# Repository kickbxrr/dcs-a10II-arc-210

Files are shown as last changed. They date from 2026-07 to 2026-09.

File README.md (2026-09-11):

# DCS ARC-210 Radio head

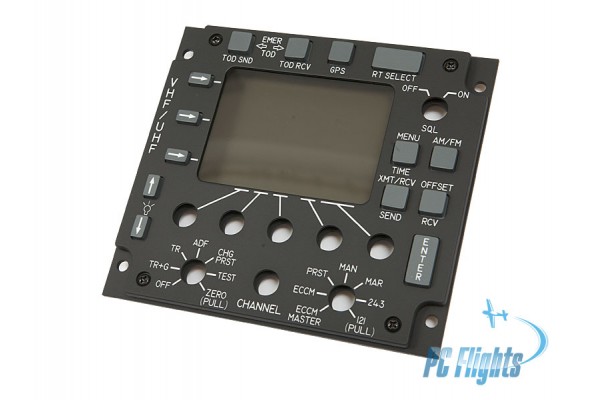
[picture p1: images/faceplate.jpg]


I got this faceplate from **SFSauto** on etsy [A10 ARC210](https://www.etsy.com/listing/1082384231/a10-thunderbolt-left-console-vhf-uhf),
but it seem like either this guy makes them for PC flights.com or got them from them. They are also available
from [PC flights.com](https://pcflights.com), direct link [a-10c-thunderbolt-warthog-vhf-uhf-panel](https://pcflights.com/a-10c-thunderbolt-warthog-vhf-uhf-panel/)

# Summary
This project is a flight sim ARC-210 style radio panel for use with DCS.
The first target interface is USB HID joystick/game-controller input from a Raspberry Pi Pico.

The panel needs to support:
- 14 push buttons
- 7 rotary encoders, without integrated push buttons
- 2 single-pole 8-position rotary switches with 45 degree throw; 7 usable positions each and the eighth mechanically locked out
- Optional SPI display later

# Main design decision
Use the Raspberry Pi Pico for timing-sensitive and analog inputs, and use an I2C I/O expander for the simple push buttons.

There are too many inputs for a clean direct-to-GPIO design on a Raspberry Pi Pico.

Raw direct input count:

- 14 push buttons = 14 digital inputs
- 7 rotary encoders = 14 digital inputs
- 2 rotary switches = 14 digital inputs when only 7 positions per switch are enabled

That would require 42 digital inputs before allowing any pins for an SPI display.
The Pico does not have enough spare GPIO for that approach.

Initeial hardware allocation:

- Raspberry Pi Pico direct GPIO:
  - 7 rotary encoders, 2 GPIO per encoder
  - SPI display pins reserved for future use
  - I2C SDA/SCL for the I/O expander
- Raspberry Pi Pico ADC:
  - 8-position rotary switch 1 through an analog resistor ladder
  - 8-position rotary switch 2 through an analog resistor ladder
  - GP28 / ADC2 **spare**
- MCP23017 I2C I/O expander:
  - 14 push buttons
  - 2 spare expanded digital inputs

# Pico pin allocation
The following allocation keeps all seven encoders on direct Pico GPIO,
places the selector ladders on two of the three exposed ADC pins, and
reserves a complete SPI display interface. Pin numbers in parentheses are
Raspberry Pi Pico physical header pins.

| Function | Pico GPIO | Header pins | Wiring notes |
| --- | --- | --- | --- |
| Encoder 1 | GP0, GP1 | 1, 2 | A, B; encoder common to GND |
| Encoder 2 | GP2, GP3 | 4, 5 | A, B; encoder common to GND |
| MCP23017 I2C | GP4, GP5 | 6, 7 | SDA, SCL; I2C0 at 400kHz |
| Encoder 3 | GP6, GP7 | 9, 10 | A, B; encoder common to GND |
| Encoder 4 | GP8, GP9 | 11, 12 | A, B; encoder common to GND |
| Encoder 5 | GP10, GP11 | 14, 15 | A, B; encoder common to GND |
| Encoder 6 | GP12, GP13 | 16, 17 | A, B; encoder common to GND |
| Encoder 7 | GP14, GP15 | 19, 20 | A, B; encoder common to GND |
| SPI display MISO, CS | GP16, GP17 | 21, 22 | Reserve MISO only if the chosen display supports reads |
| SPI display SCK, MOSI | GP18, GP19 | 24, 25 | SPI0 clock and data output |
| SPI display DC, RST, backlight | GP20, GP21, GP22 | 26, 27, 29 | Backlight pin supports PWM dimming |
| Selector 1 ladder | GP26 / ADC0 | 31 | Switch 1 common/wiper through 1K |
| Selector 2 ladder | GP27 / ADC1 | 32 | Switch 2 common/wiper through 1K |
| Spare GPIO / ADC | GP28 / ADC2 | 34 | Available for future analog or digital input; may be used for an MCP interrupt line |

Power and ground allocation:

- Pico pin 36 `3V3(OUT)` powers the MCP23017 and both resistor ladders.
- Use accessible Pico GND pins for the common ground circuit. Encoder commons, button returns, the MCP23017,
- Pin 33 (`AGND`) is used only for both Resistor ladders.
- Do not put 5V on any Pico GPIO, ADC, MCP23017 logic, or resistor-ladder connection.

Complete Pico wiring allocation

# I/O expander

I used the Waveshare MCP23017 IO Expansion Board I2C. This was a little pricy given the $12 prive per unit.
This is 2x the price of the Pico. There are some alternatives and if you go to a DIP you can find them for
$1.67 as of writing this doc. Using those will be a bit more work. There are also plenty of cheap alternatives
on Amazon, E-bay, Ali-express etc...

I'm using the MCP23017 for push buttons only. Rotary encoders should stay on Pico GPIO because they are timing-sensitive.

The MCP23017 adds 16 digital I/O pins while using only 2 Pico pins for I2C. The Pico remains in
charge: it asks the MCP23017 for its input state over I2C, and the MCP23017 returns a 16-bit value
where each bit represents one expander pin.

How I wired it to the Raspberry Pi Pico:
```text
Pico 3V3  -> MCP23017 VCC
Pico GND  -> MCP23017 GND
Pico SDA  -> MCP23017 SDA
Pico SCL  -> MCP23017 SCL

Each push button:
MCP23017 input pin -> button -> GND
```

Use `GP4` for SDA and `GP5` for SCL. The Arduino sketch configures this I2C0 bus at 400kHz.
The Waveshare board should provide the required I2C pull-ups; do not add more pull-ups until
the board documentation has been checked.

Configure the MCP23017 inputs with internal pull-ups in firmware. No external pull-up resistors
are required for the 14 buttons. A pressed button should read low.

Button state logic:

```text
button not pressed = input reads HIGH / 1
button pressed     = input connected to GND, reads LOW / 0
```

Suggested button pin mapping be based on the exact MCP23017 chip you use. In my original prototype where I just used wires to connect everyting used whatever was convienent

For my PCB, I think I used GPB0-7 and GPA0-5.

MCP23017 14-button wiring

## Polling versus interrupts

Selected approach: poll the MCP23017 every 5ms and debounce each button in firmware for about 20-30ms.

Polling is the preferred first implementation because it needs no additional Pico GPIO or wiring, is easy to debug, and has more than enough response speed for panel buttons. At a 5ms interval, a press is seen within 5ms before debounce; the I2C traffic and Pico CPU cost are negligible.

The MCP23017 interrupt outputs are useful only if future firmware needs to avoid idle I2C reads, put the Pico to sleep, or manages several expanders. Interrupts add an extra wire and more firmware state: switch bounce can cause repeated interrupts, and the Pico must read the MCP23017 `GPIO` or `INTCAP` register to clear the asserted interrupt.

Do not wire the interrupt output for the first version. A future version can connect mirrored, open-drain `INTA`/`INTB` to spare `GP28`, with a 3.3V pull-up, if interrupt-driven input becomes useful.

Button event flow:

```text
Button press
  -> MCP23017 input pin goes LOW
  -> Pico reads MCP23017 over I2C
  -> Pico sees that bit changed from 1 to 0
  -> Pico debounces the change
  -> Pico sends USB HID joystick button pressed to DCS
```

Run the MCP23017 board at 3.3V with the Pico. Keeping the control wiring at 3.3V avoids level-safety issues because Pico GPIO are not 5V tolerant.

I picked the Waveshare board over a generic MCP23017 module because it is documented, exposes address selection, and exposes interrupt pins. The interrupt pins are optional; simple polling is acceptable for push buttons.

Multiple MCP23017 boards can share the same Pico I2C bus if they have different I2C addresses. The MCP23017 supports address selection with A0/A1/A2, which allows up to 8 MCP23017 devices on the same bus.

# 8-position rotary switches (seven enabled positions)

The two 8-position switches are single-pole 8-position rotary switches.

Known switch specifications:

- Voltage rating: 125V
- Current rating: 2.5A AC, 350mA DC
- Actuator type: flatted, 6.35mm diameter
- Actuator length: 38mm
- Depth behind panel: 14.48mm
- Panel cutout: circular, 9.80mm diameter
- Number of positions: 8
- Angle of throw: 45 degrees

Recommended wiring approach: use each switch as an ADC resistor ladder so each rotary switch consumes
one Pico ADC input instead of seven digital inputs.

The eighth physical switch position is mechanically locked out. The circuit therefore provides
seven valid selector readings. Wire the disabled eighth throw to GND as an invalid diagnostic value,
rather than leaving it floating.

## Resistor ladder concept
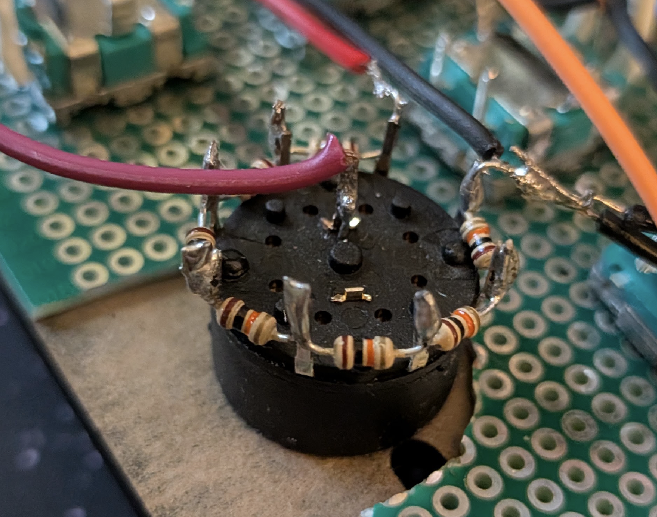
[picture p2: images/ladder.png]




The Pico ADC reads voltage. A resistor ladder creates a set of known voltages between 3.3V and GND. The rotary switch selects one of those voltage taps and sends it to the ADC input.

Use one resistor ladder per switch. The two switches cannot share a ladder because each common/wiper needs an independent ADC voltage at the same time.

Resistor ladder:
```text
3V3
 |
[10k]
 |---- switch throw 7  ~2.89V
[10k]
 |---- switch throw 6  ~2.48V
[10k]
 |---- switch throw 5  ~2.06V
[10k]
 |---- switch throw 4  ~1.65V
[10k]
 |---- switch throw 3  ~1.24V
[10k]
 |---- switch throw 2  ~0.83V
[10k]
 |---- switch throw 1  ~0.41V
[10k]
 |
GND
```

The switch common/wiper is the output:

```text
Switch common/wiper -> 1k resistor -> Pico ADC input
Pico ADC input -> 100nF capacitor -> GND
```

The 1k resistor protects the ADC input from brief wiring or contact transients. The 100nF capacitor smooths noise and contact chatter, and provides a low-impedance source while the Pico ADC samples. A pulldown is not required. Do not use a 100k pulldown: it would load the ladder and shift the expected voltages. A 1M pulldown is optional only if it is bought separately.

## Recommended parts

For each rotary switch:

- 8x 10k ohm resistors, for the ladder
- Small perfboard or stripboard
- 24-26 AWG hookup wire
- *Optional* 3-pin connector for 3V3, GND, and ADC signal

Use the available 10k resistors for the ladder in series with the ADC. With 8 x 10k resistors,
the ladder is 80k total and draws about 41uA from 3.3V. The voltage steps are wide enough for
reliable detection while keeping current draw low.

## Assembly steps
1. Use a multimeter to identify the switch common/wiper pin.
2. Build the 8-resistor chain on a small perfboard.
3. Connect the top of the chain to Pico 3V3.
4. Connect the bottom of the chain to the common ground circuit that returns to Pico physical pin 23.
5. Run one wire from each of the seven ladder taps to the corresponding active switch throw terminal.
6. Run the switch common/wiper through a 1k resistor to the Pico ADC pin.
7. Put a 100nF capacitor from the ADC pin side of the 1k resistor to GND.
8. Wire the locked-out eighth switch terminal directly to GND so it decodes as an invalid position if it is ever reached.
9. In firmware, read the ADC and map voltage ranges to positions 1-7.

**Suggested** Pico ADC allocation:

```text
Switch 1 common/wiper -> Pico GP26 / ADC0
Switch 2 common/wiper -> Pico GP27 / ADC1
Spare                  -> Pico GP28 / ADC2
```

## Expected ADC values
For a 12-bit ADC reading from 0-4095, approximate values are:

```text
Position 1:  512
Position 2: 1024
Position 3: 1536
Position 4: 2048
Position 5: 2559
Position 6: 3071
Position 7: 3583
Locked-out position: approximately 0 (invalid)
```

Firmware should define threshold ranges for each position instead of checking exact values. A good starting point is to place each threshold halfway between adjacent expected values, then require the decoded position to remain stable for 20-50ms before accepting the change.

## Interface to DCS

Initial recommendation: USB HID joystick/game-controller firmware using Arduino with the Arduino-Pico core.

Benefits:

- Simple host-side setup
- DCS can bind buttons, encoders, and selector pulses through normal controller bindings
- No DCS-specific protocol required for the first version

DCS-BIOS may be worth considering later if the project needs bidirectional state, display synchronization, 
or aircraft-specific radio data. this will be necvessary when the SPI display is added.

# Firmware stack

Selected stack: Arduino IDE with the Arduino-Pico core.

This is the final firmware environment because the project is a USB HID game-controller device. Arduino-Pico provides
a familiar sketch workflow while retaining C++ performance and offering built-in 
USB joystick, keyboard, and mouse support. It is a practical fit on both Windows 11 and macOS. Also I am more familar with 
the C++ environment of Arduino than Python or CMake.

Suggested implementation order:

1. Bring up the Pico in Arduino IDE with the Arduino-Pico board package.
2. Scan the I2C bus and confirm the MCP23017 address, expected to be `0x27` unless its address jumpers are changed. this got me at first since the AI wanted it to be `0x20` and I had to do a lot of looking up the datasheet to find the right address.
3. Configure the 14 MCP23017 pins as `INPUT_PULLUP`; poll both ports every 5ms and debounce button state changes for 20-30ms.
4. Read the two selector ADC inputs; decode selector positions by threshold range and require a stable reading for 20-50ms.
5. Read the seven encoders directly from Pico GPIO.
6. Send button, selector, and encoder events through USB HID to DCS.

Why Arduino-Pico instead of the Pico SDK:

- Arduino-Pico is C++ with a straightforward sketch, library, compile, and upload workflow. It is easier to iterate on than a standalone CMake project.
- It already provides the USB HID joystick/game-controller capability this panel needs.
- The Pico SDK provides the most control over low-level timing and custom USB descriptors, but its toolchain and CMake project setup are more involved. It remains a good future option if this panel eventually needs a custom HID report beyond what Arduino-Pico provides.

Windows 11 and macOS are both suitable for Arduino-Pico. The finished Pico appears to the computer as a standard USB HID device, so DCS does not need a special driver.

## Initial controller sketch
The initial Arduino sketch is [arc210_controller.ino](./arc210_controller/arc210_controller.ino).

Arduino IDE setup:

1. Install the Arduino-Pico board package and select `Raspberry Pi Pico`.
2. Set `Tools -> USB Stack -> Pico SDK`; the Arduino-Pico `Joystick` library is provided by this USB stack.
3. Install `Adafruit MCP23X17` from Library Manager. Its dependencies, including Adafruit BusIO, should install automatically.
4. Upload the sketch with the Pico connected by USB.

The sketch presents one USB joystick with all 32 buttons used and no analog control assigned:

| HID controls | Source |
| --- | --- |
| Buttons 1-14 | MCP23017 push buttons |
| Buttons 15-26 | Encoder 1-6 positive and negative turns |
| Buttons 27-28 | Encoder 7 positive and negative turns |
| Buttons 29-30 | Selector 1 next and previous position pulses |
| Buttons 31-32 | Selector 2 next and previous position pulses |

The Arduino-Pico joystick descriptor supports 32 buttons, so this allocation uses its entire button capacity. The selectors intentionally emit relative next/previous pulses instead of using fourteen more held buttons, keeping the design within that limit. Bind each selector's next/previous buttons to the matching DCS increment/decrement commands. On startup, align the simulator state with the physical selector positions manually.

## Open items before final schematic

- SPI display model and pin requirements
- Find suitable display

## Initial Prototype
The initial prototype was done on perf boards. I found ut the hard way that drilling and cutting perfboards can have 
some consequences.The worse was getting a few fiberglass splinters. The Pico was mounted on 2 1x20 sockets 
(Technically it was 4 1x10 connectors that I sanded to fit and work like 2 1x20 connectors), and the MCP23017 
was mounted on 2 1x10 connectors.The components are just soldiered together using random wires. the whole thing 
is kind of a mess. It works but it is ugly.

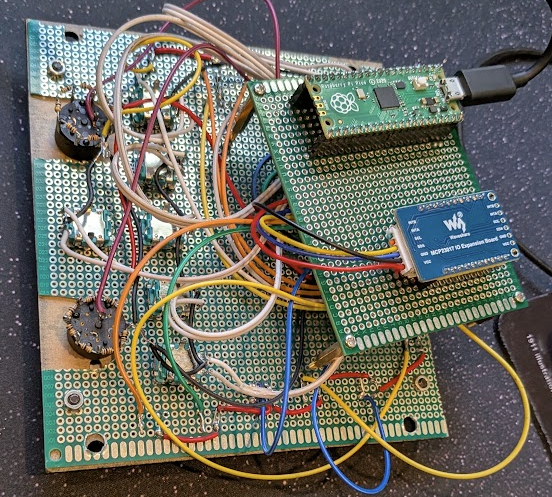
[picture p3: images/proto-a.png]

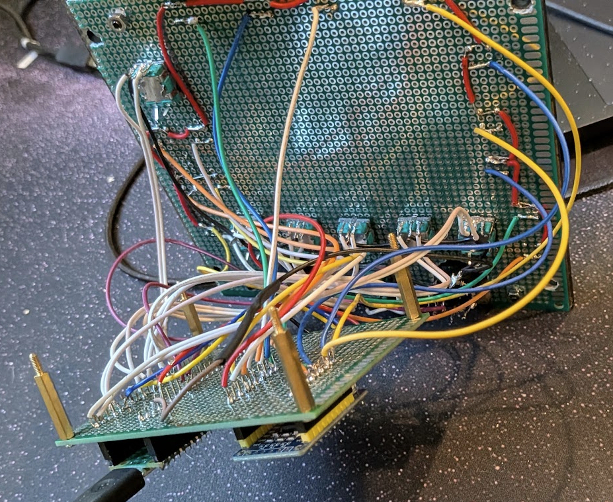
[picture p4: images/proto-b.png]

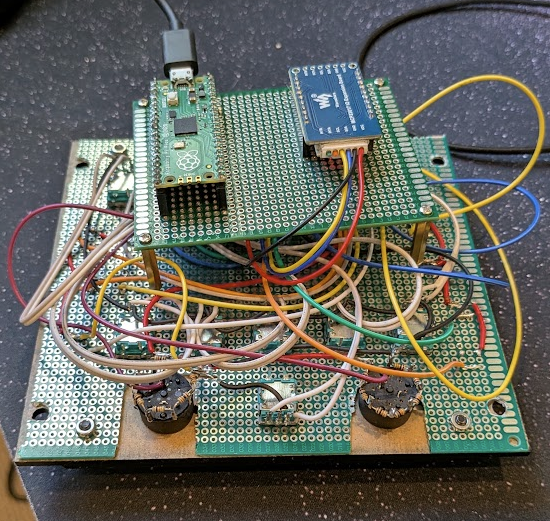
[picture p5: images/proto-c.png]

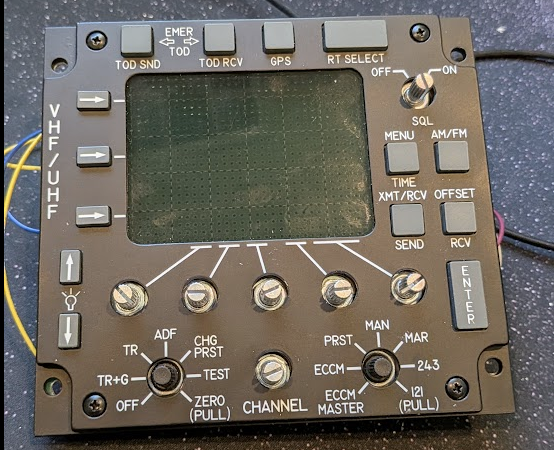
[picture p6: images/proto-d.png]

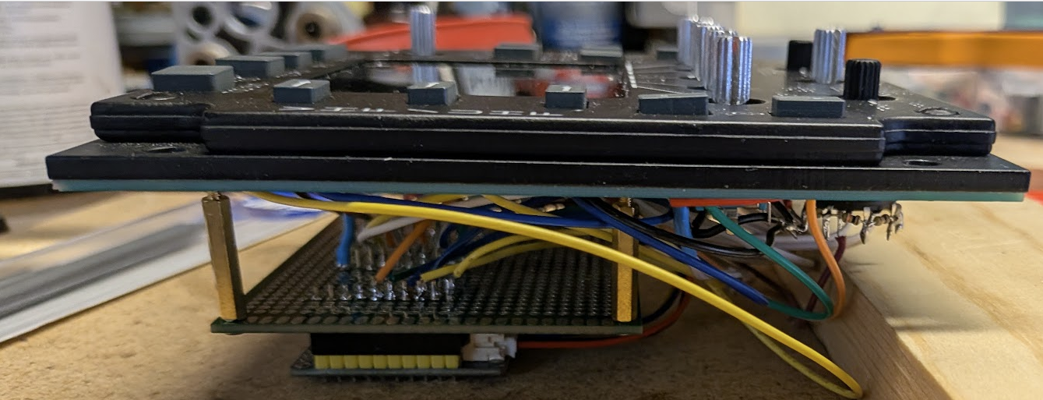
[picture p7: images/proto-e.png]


# Phase 2 PCB
I figured it would be cool to see if I can create a PCB.
Watching some youtube videos from the Warthog project and
some DCS community videos of people build button boxes and
different panels made me think I could clean this up a lot.

# Schematic
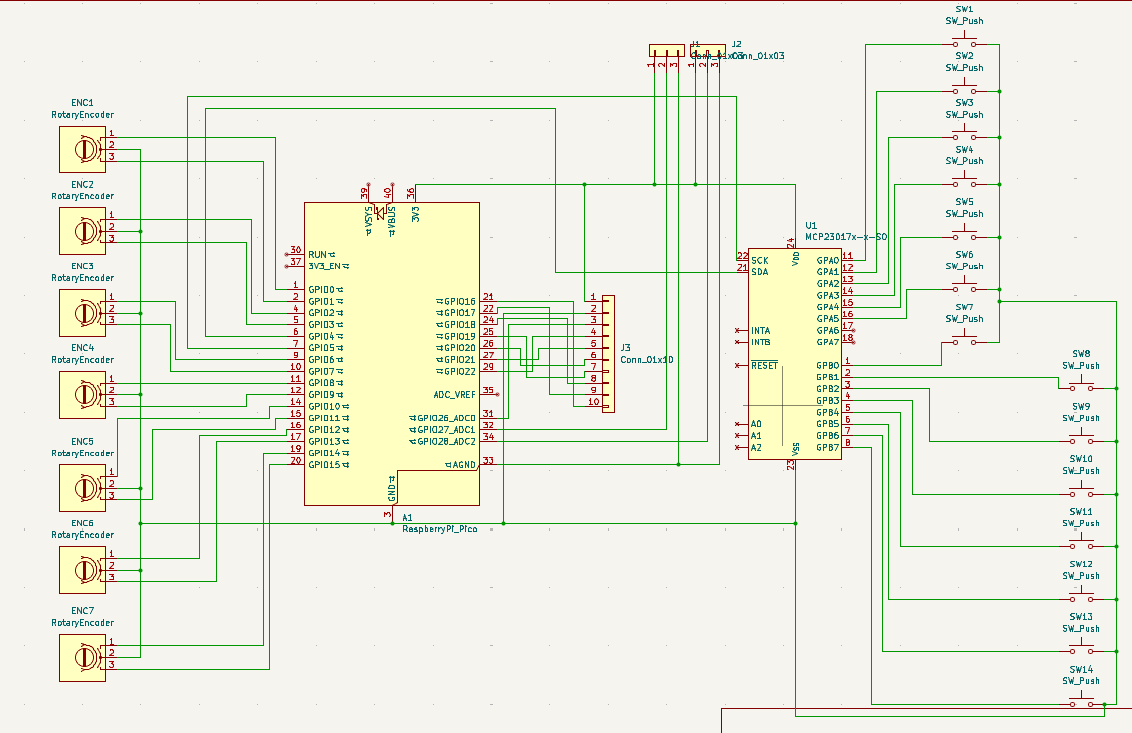
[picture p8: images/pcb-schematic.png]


## PCB Rev B work

The first PCB revision is a panel-sized button carrier. The 14 tactile
buttons mount directly to the PCB; the seven encoders and two selectors
remain faceplate-mounted and connect through cutouts in the PCB. Maybe if
I try to do another prototype I will try surface mounting the compnenets
and try to get an assempled board with all the part already on the board. 
this feel like a big leap from I was hand ouldering crap from perfboards with
a rats nest of wires 3 weeks ago to producing a full PCBA board

Rev B uses a removable Raspberry Pi Pico in two 1x20 sockets,
a socketed MCP23017-E/SP DIP-28 IC, and provisional 6x6mm
tactile-switch footprints. It was ready for fabrication pretty quick.
I', pretty sure my trace routing needs some help, but all the button work
as expected so that is a win in my book.

## Kicad
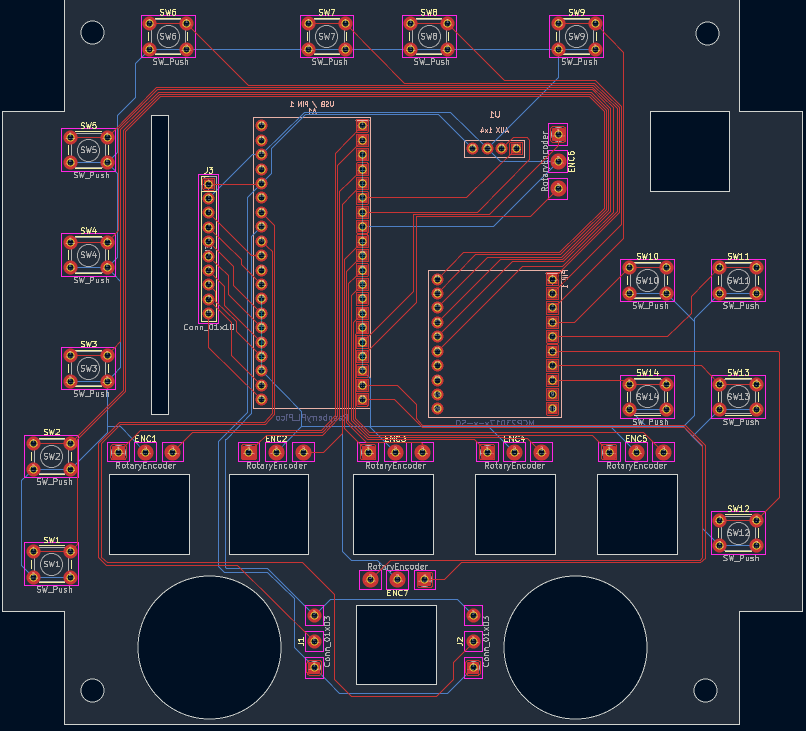
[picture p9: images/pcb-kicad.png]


### 3D Front
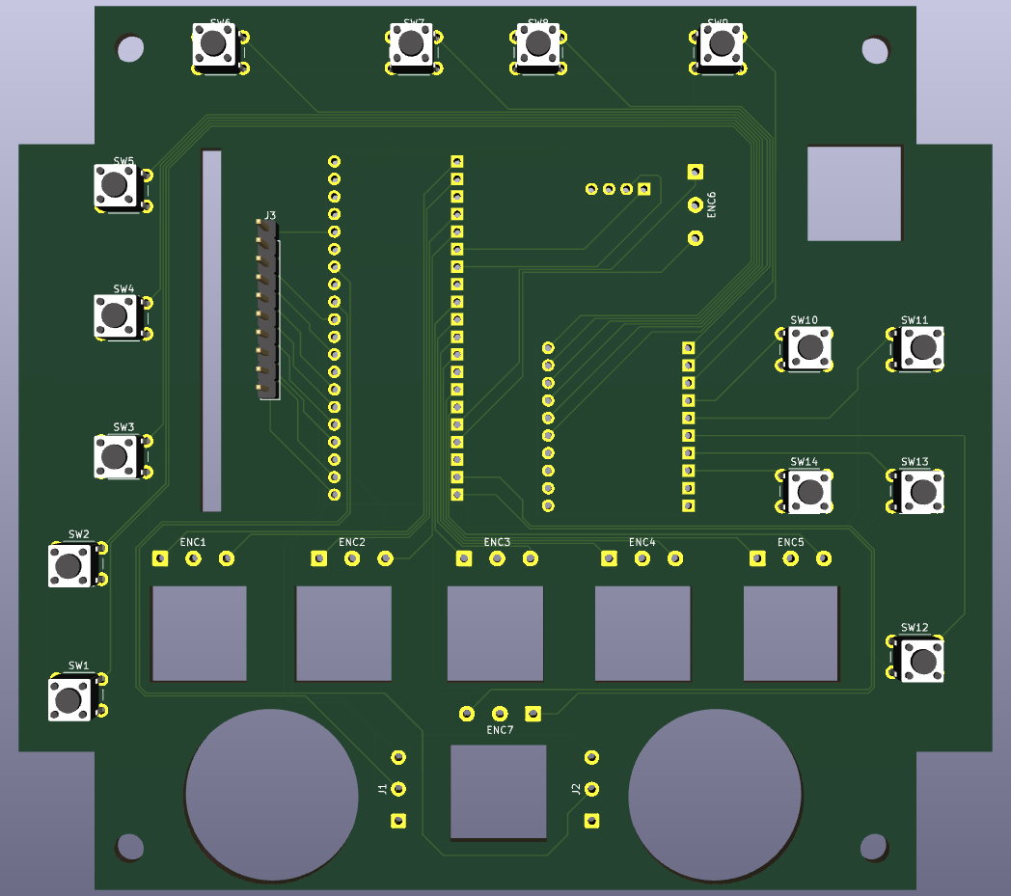
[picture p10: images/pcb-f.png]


### 3d Back
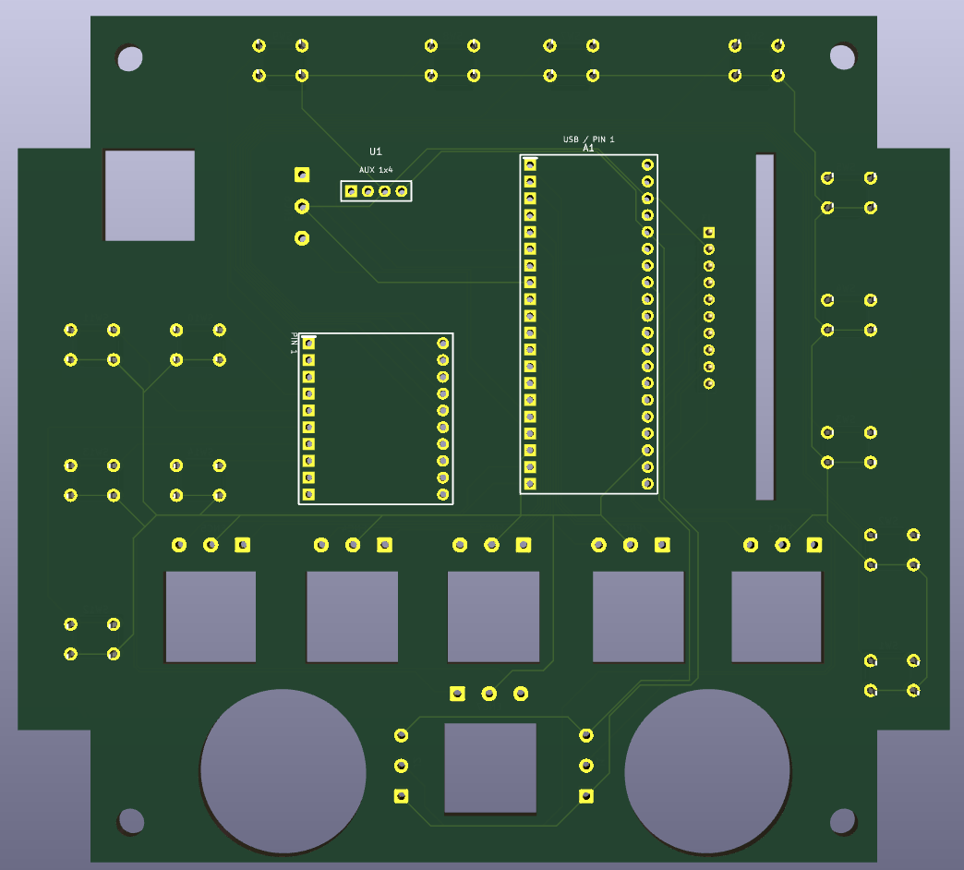
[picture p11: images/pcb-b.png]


### Actual PCB Front
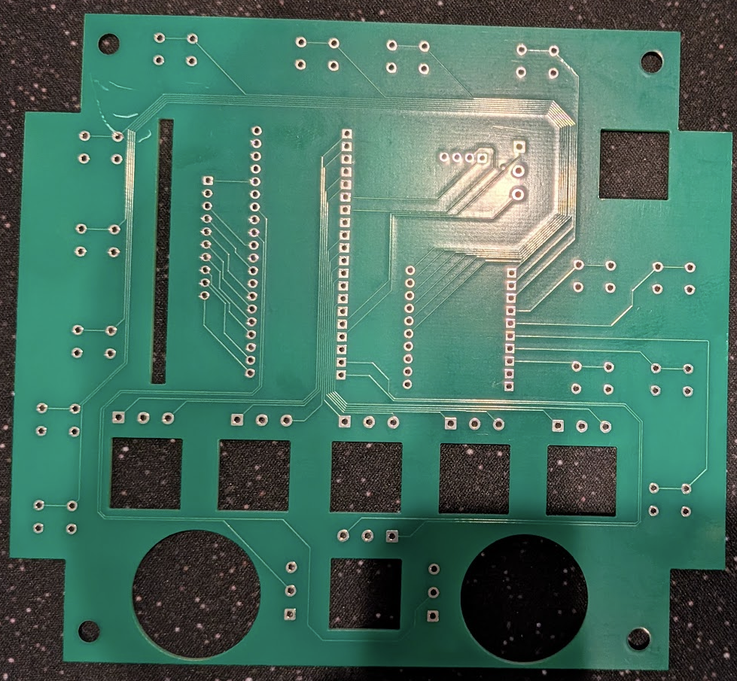
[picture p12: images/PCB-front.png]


### Actual PCB Back
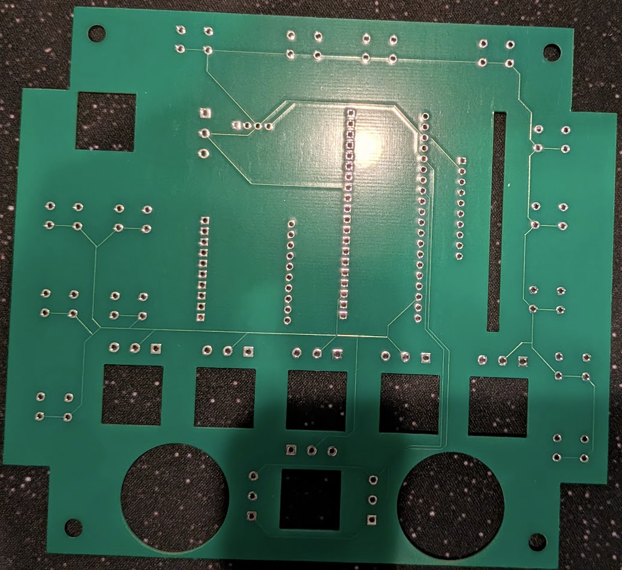
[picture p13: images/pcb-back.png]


## SPI display `Phase 3`
The design reserves pins for a SPI display. A typical SPI display may need:

- SCK
- MOSI
- CS
- DC
- optional RST
- optional backlight control

Using the MCP23017 for push buttons keeps enough Pico pins available for the display.
Direct-to-GPIO wiring for all buttons and switch positions would make the SPI display
difficult to add if impossible.

For the display I get a 3.5" TFT display from Amazon. I did some surgery to remove the display
from the controller board. I figured I would destroy one of the two boards but in a stroke of luck
I got it sorted out on the 1st try.

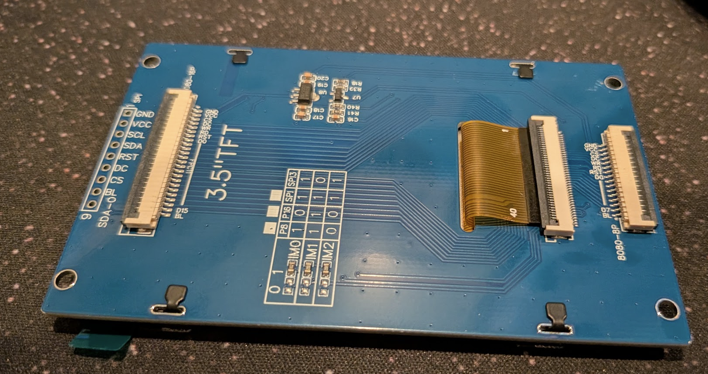
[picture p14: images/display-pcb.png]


# How did it all turn out?
TBD!!!

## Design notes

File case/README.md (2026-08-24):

# ARC-210 open-top tray

`arc210_open_tray.scad` is an editable OpenSCAD model for a 3D-printed case:

- Overall size: 146 mm wide x 133 mm high x 40 mm deep
- Wall thickness: 2 mm
- Floor thickness: 3 mm
- Open top
- 2 mm outside corner radius, matching the SVG outline
- Four 28 mm-deep corner mounting features: an 8 mm top pad plus a 20 mm
  wall-to-pad transition at 45° or steeper, with 6 mm-rounded inside corners
- Four 6 mm through-holes at the SVG's M1-M4 locations; each passes through
  the full 8 mm mounting pad

## Exporting an STL

1. Open `arc210_open_tray.scad` in OpenSCAD.
2. Press **F6** to render the model.
3. Choose **File → Export → Export as STL**.

The hole locations, diameter, pad thickness, and gusset depth are parameters
near the top of the SCAD file and can be changed before exporting.

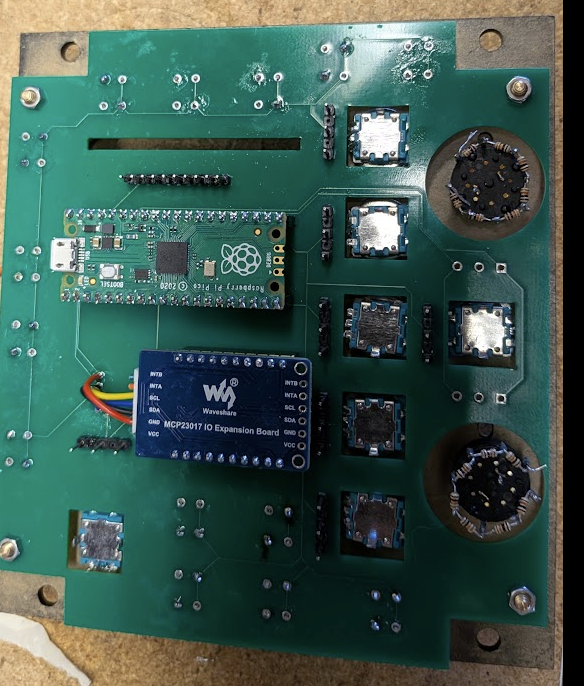
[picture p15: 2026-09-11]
images/proto-b-3.png

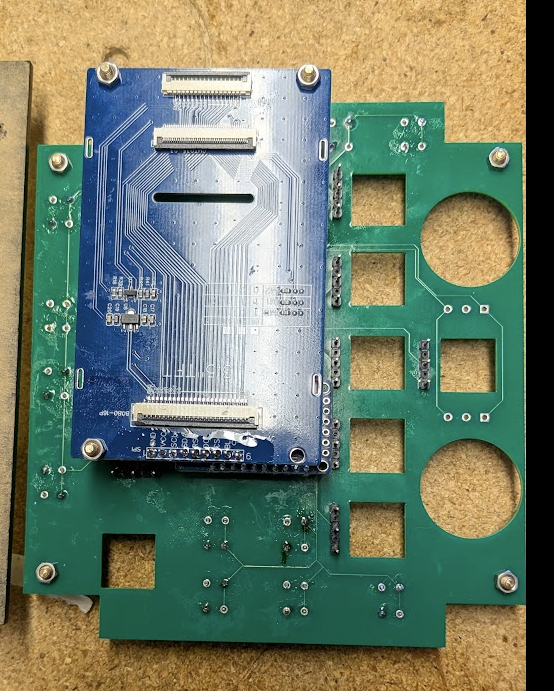
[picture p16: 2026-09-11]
images/proto-b.1-1.png

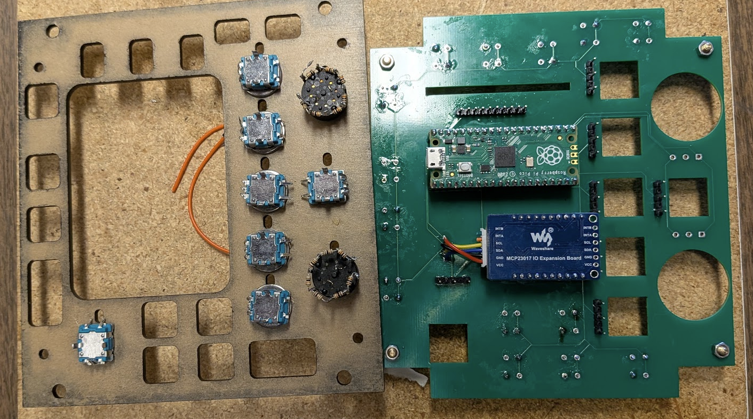
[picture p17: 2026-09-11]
images/proto-b-1.png

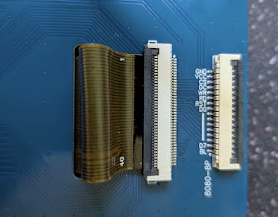
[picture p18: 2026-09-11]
images/proto-zif.png

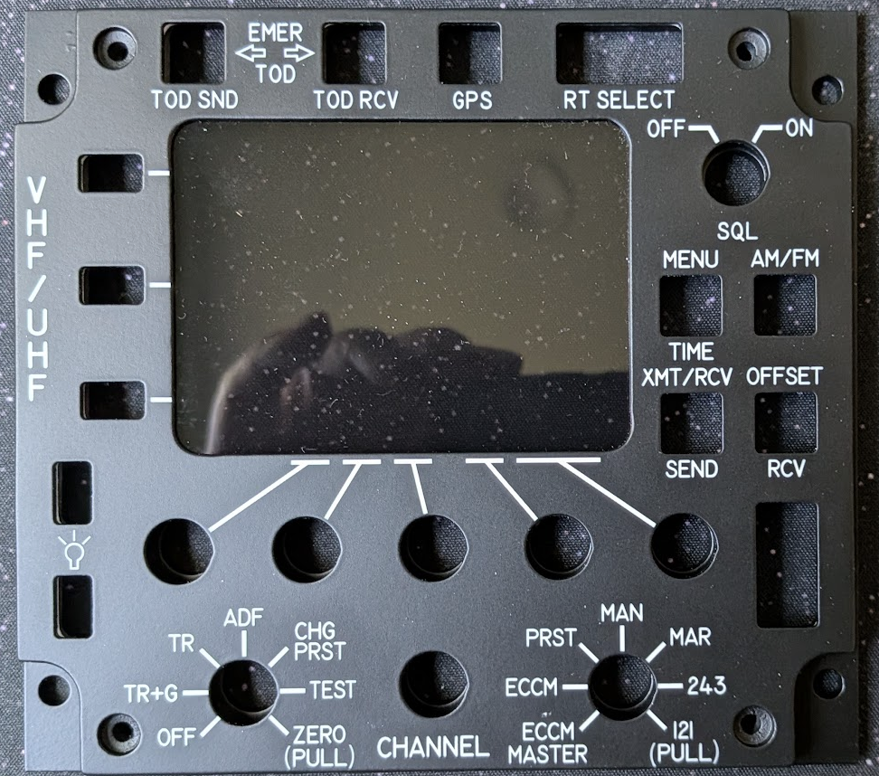
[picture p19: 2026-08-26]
images/faceplate-actual.png

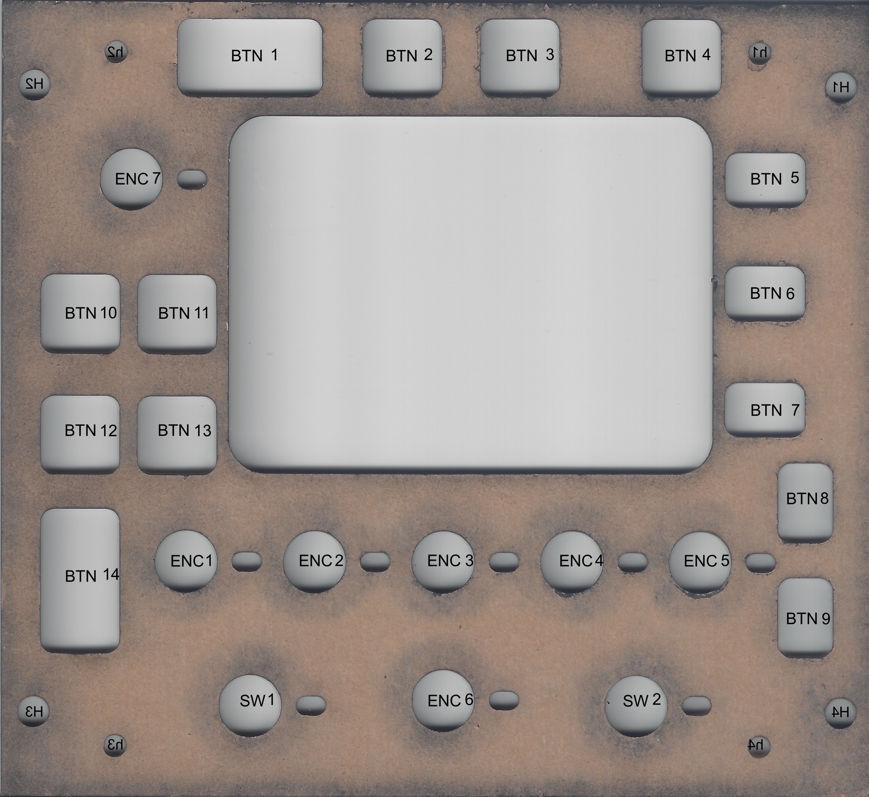
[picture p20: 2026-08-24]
images/scanofbackplate.jpg

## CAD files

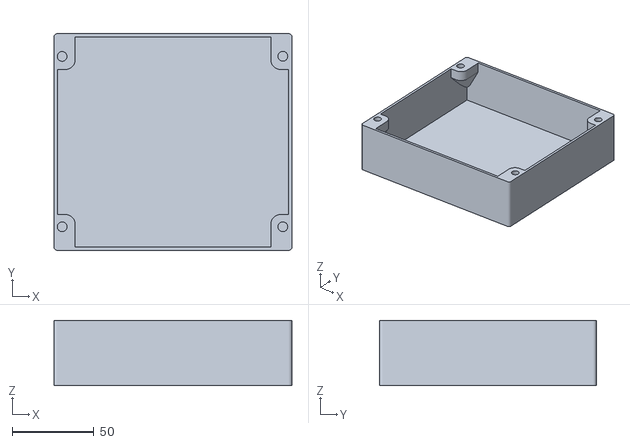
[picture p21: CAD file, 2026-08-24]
case/arc210_open_tray.stl
146.0 x 133.0 x 40.0

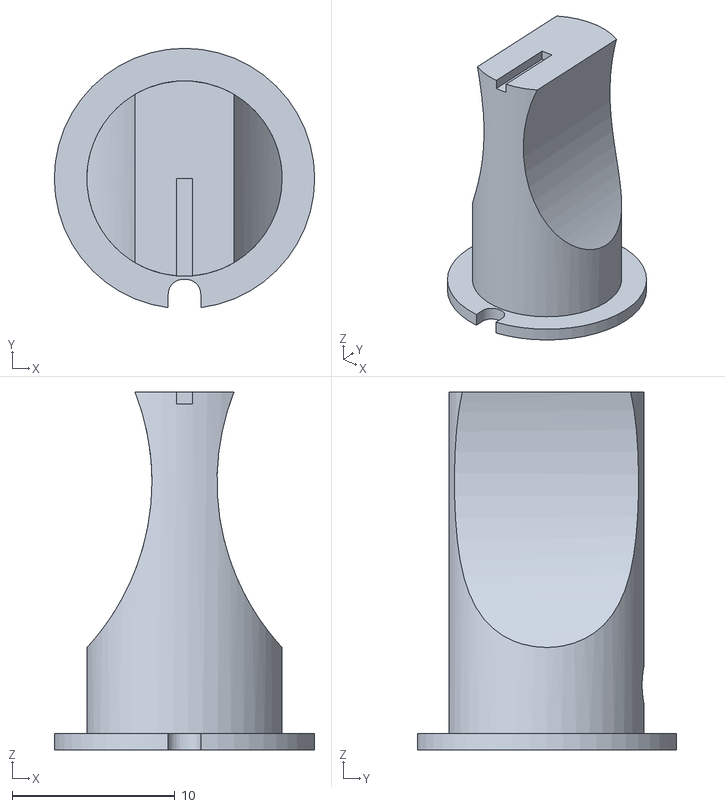
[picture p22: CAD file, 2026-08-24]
knobs/ARC-210_Mode_Knob_shaft-depth-8.2mm.stl
16.0 x 15.9 x 22.0

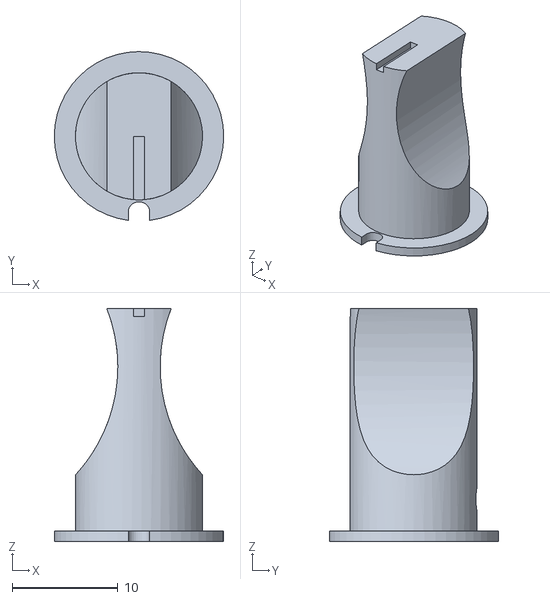
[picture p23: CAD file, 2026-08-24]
knobs/ARC-210 Mode Knob.stl
16.0 x 15.9 x 22.0

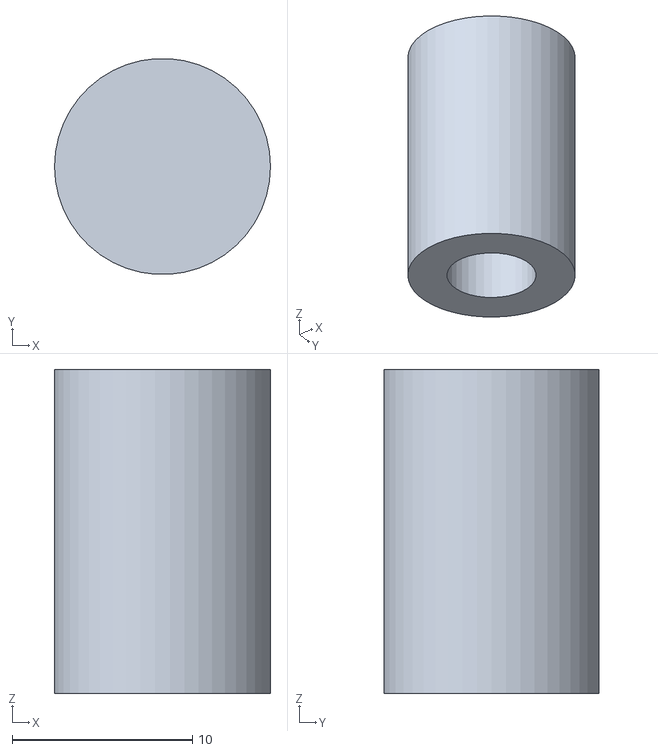
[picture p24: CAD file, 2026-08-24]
knobs/ARC-210 Channel Knob.stl
12.0 x 12.0 x 18.0

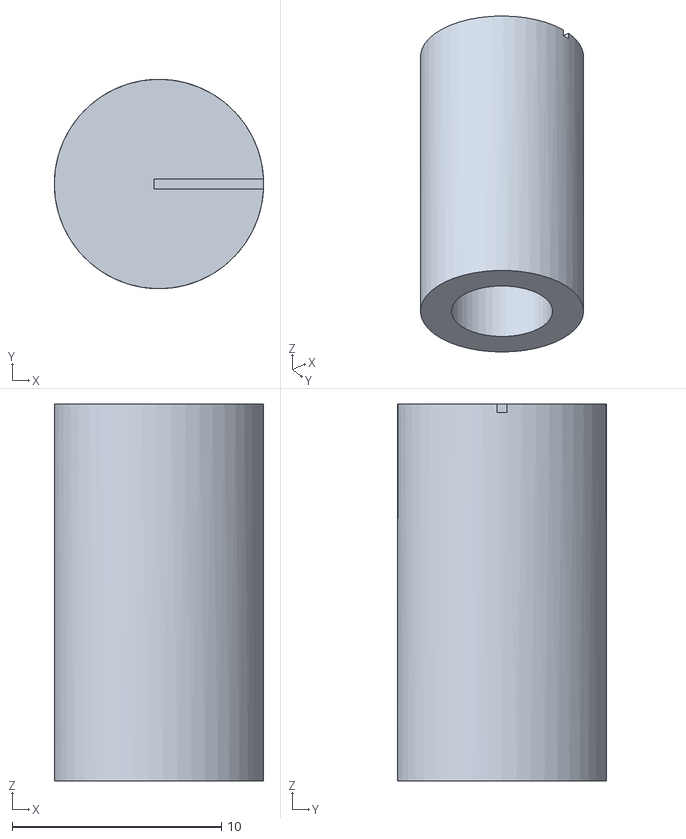
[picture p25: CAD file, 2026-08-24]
knobs/ARC-210 Squelch Knob.stl
10.0 x 10.00 x 18.0

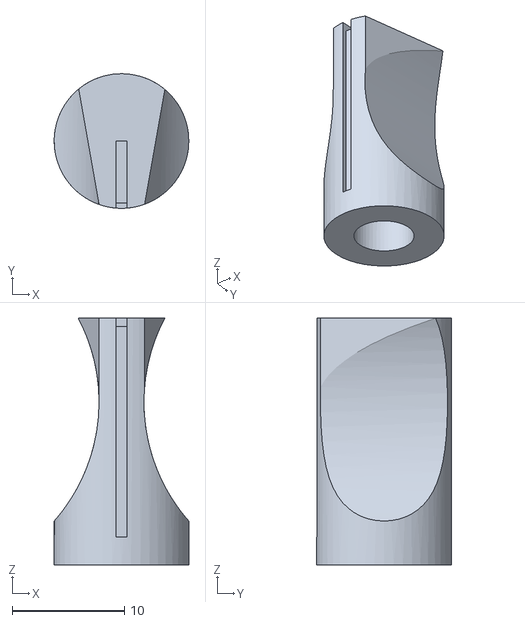
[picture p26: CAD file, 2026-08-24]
knobs/ARC-210 Freq Knob.stl
12.0 x 12.0 x 22.0

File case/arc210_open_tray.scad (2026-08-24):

// ARC-210 shallow open-top case
// Units: millimetres
// The XY outline matches the 146 x 133 mm faceplate template; Z is depth.

outer_width = 146;
outer_height = 133;
case_depth = 40;
wall_thickness = 2;
floor_thickness = 3;
outer_corner_radius = 2;

// Through-holes matching the M1-M4 locations in the SVG. They pass through
// the upper mounting pads from the open/top face.
mounting_hole_diameter = 6;  // SVG radius is 3 mm
mounting_feature_depth = 28; // 20 mm taper + 8 mm top pad
mounting_pad_thickness = 8;  // flat top pad; holes pass through this section
mounting_gusset_height = mounting_feature_depth - mounting_pad_thickness;
mounting_holes = [
    [5.0, 14.5],    // M1
    [140.4, 14.5],  // M2
    [5.0, 119.0],   // M3
    [140.4, 119.1]  // M4
];

// The SVG's four black mounting blocks are clipped 26 x 44 mm rounded
// rectangles whose centres sit on the corners of the faceplate.
corner_block_width = 26;
corner_block_height = 44;
corner_block_radius = 6;
corner_blocks = [
    [-13, -22],
    [133, -22],
    [-13, 111],
    [133, 111]
];
corner_outward_shifts = [
    [-11, -20],
    [11, -20],
    [-11, 20],
    [11, 20]
];

module rounded_rectangle(size, radius) {
    translate([radius, radius])
        offset(r = radius)
            square([size[0] - 2*radius, size[1] - 2*radius]);
}

module outer_profile() {
    rounded_rectangle([outer_width, outer_height], outer_corner_radius);
}

module wall_profile() {
    // The 2 mm perimeter walls continue through the full case depth.
    intersection() {
        outer_profile();
        union() {
            square([outer_width, wall_thickness]);
            translate([0, outer_height - wall_thickness])
                square([outer_width, wall_thickness]);
            square([wall_thickness, outer_height]);
            translate([outer_width - wall_thickness, 0])
                square([wall_thickness, outer_height]);
        }
    }
}

module corner_profile(p) {
    intersection() {
        outer_profile();
        translate(p)
            rounded_rectangle(
                [corner_block_width, corner_block_height],
                corner_block_radius);
    }
}

module mounting_profile() {
    // Full mounting-pad footprint, used for the top 8 mm.
    intersection() {
        outer_profile();
        union() {
            for (p = corner_blocks)
                corner_profile(p);
        }
    }
}

module mounting_gussets() {
    // Each gusset starts at the inside faces of the 2 mm walls and grows to
    // the pad over 20 mm of height. The limiting direction is exactly 45°;
    // the other direction is steeper and therefore also support-free.
    for (i = [0 : len(corner_blocks) - 1])
        hull() {
            p = corner_blocks[i];
            s = corner_outward_shifts[i];
            translate([0, 0, case_depth - mounting_feature_depth])
                linear_extrude(height = 0.01)
                    corner_profile([p[0] + s[0], p[1] + s[1]]);
            translate([0, 0, case_depth - mounting_pad_thickness])
                linear_extrude(height = 0.01)
                    corner_profile(p);
        }
}

module case_body() {
    difference() {
        union() {
            // Full outer-profile floor, full-height walls, and upper pads.
            linear_extrude(height = floor_thickness)
                outer_profile();
            linear_extrude(height = case_depth)
                wall_profile();
            translate([0, 0, case_depth - mounting_pad_thickness])
                linear_extrude(height = mounting_pad_thickness)
                    mounting_profile();
            mounting_gussets();
        }

        // Through-holes in the upper 8 mm mounting pads. The small overlap at
        // either end guarantees a clean cut through the pad surfaces.
        for (p = mounting_holes)
            translate([p[0], p[1], case_depth - mounting_pad_thickness - 0.1])
                cylinder(h = mounting_pad_thickness + 0.2,
                         d = mounting_hole_diameter,
                         $fn = 48);
    }
}

case_body();

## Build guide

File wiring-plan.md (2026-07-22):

# ARC-210 wiring plan

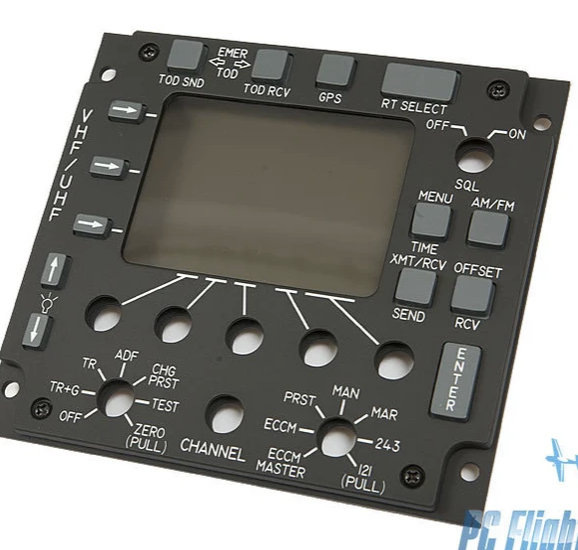
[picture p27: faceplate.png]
panel


# Summary

This project is a flight sim ARC-210 style radio panel for use with DCS. The first target interface is USB HID joystick/game-controller input from a Raspberry Pi Pico.

The panel needs to support:

- 14 push buttons
- 7 rotary encoders, without integrated push buttons
- 2 single-pole 8-position rotary switches with 45 degree throw; 7 usable positions each and the eighth mechanically locked out
- Optional SPI display later

# Main design decision

There are too many inputs for a clean direct-to-GPIO design on a Raspberry Pi Pico.

Raw direct input count:

- 14 push buttons = 14 digital inputs
- 7 rotary encoders = 14 digital inputs
- 2 rotary switches = 14 digital inputs when only 7 positions per switch are enabled

That would require 42 digital inputs before allowing any pins for an SPI display. The Pico does not have enough spare GPIO for that approach.

# Recommended architecture

Use the Pico for timing-sensitive and analog inputs, and use an I2C I/O expander for the simple push buttons.

Recommended allocation:

- Raspberry Pi Pico direct GPIO:
  - 7 rotary encoders, 2 GPIO per encoder
  - SPI display pins reserved for future use
  - I2C SDA/SCL for the I/O expander
- Raspberry Pi Pico ADC:
  - 8-position rotary switch 1 through an analog resistor ladder
  - 8-position rotary switch 2 through an analog resistor ladder
  - GP28 / ADC2 remains spare
- MCP23017 I2C I/O expander:
  - 14 push buttons
  - 2 spare expanded digital inputs

# Exact Pico pin allocation

The following allocation keeps all seven encoders on direct Pico GPIO, places the selector ladders on two of the three exposed ADC pins, and reserves a complete SPI display interface. Pin numbers in parentheses are Raspberry Pi Pico physical header pins.

| Function | Pico GPIO | Header pins | Wiring notes |
| --- | --- | --- | --- |
| Encoder 1 | GP0, GP1 | 1, 2 | A, B; encoder common to GND |
| Encoder 2 | GP2, GP3 | 4, 5 | A, B; encoder common to GND |
| MCP23017 I2C | GP4, GP5 | 6, 7 | SDA, SCL; I2C0 at 400kHz |
| Encoder 3 | GP6, GP7 | 9, 10 | A, B; encoder common to GND |
| Encoder 4 | GP8, GP9 | 11, 12 | A, B; encoder common to GND |
| Encoder 5 | GP10, GP11 | 14, 15 | A, B; encoder common to GND |
| Encoder 6 | GP12, GP13 | 16, 17 | A, B; encoder common to GND |
| Encoder 7 | GP14, GP15 | 19, 20 | A, B; encoder common to GND |
| SPI display MISO, CS | GP16, GP17 | 21, 22 | Reserve MISO only if the chosen display supports reads |
| SPI display SCK, MOSI | GP18, GP19 | 24, 25 | SPI0 clock and data output |
| SPI display DC, RST, backlight | GP20, GP21, GP22 | 26, 27, 29 | Backlight pin supports PWM dimming |
| Selector 1 ladder | GP26 / ADC0 | 31 | Switch 1 common/wiper through 1K |
| Selector 2 ladder | GP27 / ADC1 | 32 | Switch 2 common/wiper through 1K |
| Spare GPIO / ADC | GP28 / ADC2 | 34 | Available for future analog or digital input; may be used for an MCP interrupt line |

Power and ground allocation:

- Pico pin 36 `3V3(OUT)` powers the MCP23017 and both resistor ladders.
- Use accessible Pico GND pin 23 for the common ground circuit. Pin 33 (`AGND`) is not used. Encoder commons, button returns, the MCP23017, both selector ladders, and their 100nF capacitors may all share this ground circuit. If selector readings later prove noisy, shorten their signal and ground wiring before making larger wiring changes.
- Do not put 5V on any Pico GPIO, ADC, MCP23017 logic, or resistor-ladder connection.

Complete Pico wiring allocation

# I/O expander

Recommended part: Waveshare MCP23017 IO Expansion Board I2C.

Use the MCP23017 for push buttons only. Rotary encoders should stay on Pico GPIO because they are timing-sensitive.

The MCP23017 adds 16 digital I/O pins while using only 2 Pico pins for I2C. The Pico remains in charge: it asks the MCP23017 for its input state over I2C, and the MCP23017 returns a 16-bit value where each bit represents one expander pin.

Suggested wiring:

```text
Pico 3V3  -> MCP23017 VCC
Pico GND  -> MCP23017 GND
Pico SDA  -> MCP23017 SDA
Pico SCL  -> MCP23017 SCL

Each push button:
MCP23017 input pin -> button -> GND
```

Use `GP4` for SDA and `GP5` for SCL. The Arduino sketch configures this I2C0 bus at 400kHz. The Waveshare board should provide the required I2C pull-ups; do not add more pull-ups until the board documentation has been checked.

Configure the MCP23017 inputs with internal pull-ups in firmware. No external pull-up resistors are required for the 14 buttons. A pressed button should read low.

Button state logic:

```text
button not pressed = input reads HIGH / 1
button pressed     = input connected to GND, reads LOW / 0
```

Suggested button pin mapping:

```text
Button 1  -> MCP23017 GPA0
Button 2  -> MCP23017 GPA1
Button 3  -> MCP23017 GPA2
Button 4  -> MCP23017 GPA3
Button 5  -> MCP23017 GPA4
Button 6  -> MCP23017 GPA5
Button 7  -> MCP23017 GPA6
Button 8  -> MCP23017 GPA7

Button 9  -> MCP23017 GPB0
Button 10 -> MCP23017 GPB1
Button 11 -> MCP23017 GPB2
Button 12 -> MCP23017 GPB3
Button 13 -> MCP23017 GPB4
Button 14 -> MCP23017 GPB5
Spare     -> MCP23017 GPB6
Spare     -> MCP23017 GPB7
```

MCP23017 14-button wiring

## Polling versus interrupts

Selected approach: poll the MCP23017 every 5ms and debounce each button in firmware for about 20-30ms.

Polling is the preferred first implementation because it needs no additional Pico GPIO or wiring, is easy to debug, and has more than enough response speed for panel buttons. At a 5ms interval, a press is seen within 5ms before debounce; the I2C traffic and Pico CPU cost are negligible.

The MCP23017 interrupt outputs are useful only if future firmware needs to avoid idle I2C reads, put the Pico to sleep, or manages several expanders. Interrupts add an extra wire and more firmware state: switch bounce can cause repeated interrupts, and the Pico must read the MCP23017 `GPIO` or `INTCAP` register to clear the asserted interrupt.

Do not wire the interrupt output for the first version. A future version can connect mirrored, open-drain `INTA`/`INTB` to spare `GP28`, with a 3.3V pull-up, if interrupt-driven input becomes useful.

Button event flow:

```text
Button press
  -> MCP23017 input pin goes LOW
  -> Pico reads MCP23017 over I2C
  -> Pico sees that bit changed from 1 to 0
  -> Pico debounces the change
  -> Pico sends USB HID joystick button pressed to DCS
```

Run the MCP23017 board at 3.3V with the Pico. Keeping the control wiring at 3.3V avoids level-safety issues because Pico GPIO are not 5V tolerant.

The Waveshare board is preferred over a generic MCP23017 module because it is documented, exposes address selection, and exposes interrupt pins. The interrupt pins are optional; simple polling is acceptable for push buttons.

Multiple MCP23017 boards can share the same Pico I2C bus if they have different I2C addresses. The MCP23017 supports address selection with A0/A1/A2, which allows up to 8 MCP23017 devices on the same bus.

Possible future expansion:

```text
MCP23017 #1 at 0x20 -> 14 push buttons + 2 spares
MCP23017 #2 at 0x21 -> optional direct digital wiring for both 8-position switches
MCP23017 #3 at 0x22 -> spare expansion or future controls
```

If the two 8-position rotary switches are moved from ADC resistor ladders to an MCP23017 later, each switch uses 8 MCP23017 inputs. Both switches fit exactly on one MCP23017:

```text
Switch 1 common/wiper -> GND
Switch 1 throws 1-8  -> MCP23017 GPA0-GPA7

Switch 2 common/wiper -> GND
Switch 2 throws 1-8  -> MCP23017 GPB0-GPB7
```

This would make each selector position a plain digital input and would free ADC0 and ADC1. It costs another MCP23017 board, so the resistor ladder approach remains the cheaper first design.

# 8-position rotary switches (seven enabled positions)

The two 8-position switches are single-pole 8-position rotary switches.

Known switch specifications:

- Voltage rating: 125V
- Current rating: 2.5A AC, 350mA DC
- Actuator type: flatted, 6.35mm diameter
- Actuator length: 38mm
- Depth behind panel: 14.48mm
- Panel cutout: circular, 9.80mm diameter
- Number of positions: 8
- Angle of throw: 45 degrees

Recommended wiring approach: use each switch as an ADC resistor ladder so each rotary switch consumes one Pico ADC input instead of seven digital inputs.

The eighth physical switch position is mechanically locked out. The circuit therefore provides seven valid selector readings. Wire the disabled eighth throw to GND as an invalid diagnostic value, rather than leaving it floating.

## Resistor ladder concept

The Pico ADC reads voltage. A resistor ladder creates a set of known voltages between 3.3V and GND. The rotary switch selects one of those voltage taps and sends it to the ADC input.

Use one resistor ladder per switch. The two switches cannot share a ladder because each common/wiper needs an independent ADC voltage at the same time.

7-position resistor ladder wiring

Physical wiring summary:

- 3V3 and GND feed the resistor ladder.
- The resistor ladder is a chain of 8 equal-value resistors between 3V3 and GND.
- The spaces between resistors are tap points, each with a different voltage.
- Seven outside switch terminals connect to the seven ladder taps.
- The locked-out eighth terminal connects directly to GND, producing an invalid ADC reading near zero if the lockout is ever defeated.
- The switch's center/common/wiper pin connects to the Pico ADC input.
- When the switch turns, it connects the ADC input to one selected ladder voltage.
- For the second 8-position switch, build the same circuit again and connect its common/wiper to a different ADC pin.

Recommended ladder:

```text
3V3
 |
[10k]
 |---- switch throw 7  ~2.89V
[10k]
 |---- switch throw 6  ~2.48V
[10k]
 |---- switch throw 5  ~2.06V
[10k]
 |---- switch throw 4  ~1.65V
[10k]
 |---- switch throw 3  ~1.24V
[10k]
 |---- switch throw 2  ~0.83V
[10k]
 |---- switch throw 1  ~0.41V
[10k]
 |
GND
```

The switch common/wiper is the output:

```text
Switch common/wiper -> 1k resistor -> Pico ADC input
Pico ADC input -> 100nF capacitor -> GND
```

The 1k resistor protects the ADC input from brief wiring or contact transients. The 100nF capacitor smooths noise and contact chatter, and provides a low-impedance source while the Pico ADC samples. A pulldown is not required. Do not use a 100k pulldown: it would load the ladder and shift the expected voltages. A 1M pulldown is optional only if it is bought separately.

## Recommended parts

For each rotary switch:

- 8x 10k ohm resistors, 1% metal film, through-hole, for the ladder
- 1x 1k ohm resistor for the ADC signal line
- 1x 100nF ceramic capacitor, X7R preferred
- Small perfboard or stripboard
- 24-26 AWG hookup wire
- Optional 3-pin connector for 3V3, GND, and ADC signal

Use the available 10k resistors for the ladder and the available 1k resistor in series with the ADC. Do not use the available 100k resistors in this circuit. With 8 x 10k resistors, the ladder is 80k total and draws about 41uA from 3.3V. The voltage steps are wide enough for reliable detection while keeping current draw low.

## Assembly steps

1. Use a multimeter to identify the switch common/wiper pin.
2. Build the 8-resistor chain on a small perfboard.
3. Connect the top of the chain to Pico 3V3.
4. Connect the bottom of the chain to the common ground circuit that returns to Pico physical pin 23.
5. Run one wire from each of the seven ladder taps to the corresponding active switch throw terminal.
6. Run the switch common/wiper through a 1k resistor to the Pico ADC pin.
7. Put a 100nF capacitor from the ADC pin side of the 1k resistor to GND.
8. Wire the locked-out eighth switch terminal directly to GND so it decodes as an invalid position if it is ever reached.
9. In firmware, read the ADC and map voltage ranges to positions 1-7.

Suggested Pico ADC allocation:

```text
Switch 1 common/wiper -> Pico GP26 / ADC0
Switch 2 common/wiper -> Pico GP27 / ADC1
Spare                  -> Pico GP28 / ADC2
```

## Expected ADC values

For a 12-bit ADC reading from 0-4095, approximate values are:

```text
Position 1:  512
Position 2: 1024
Position 3: 1536
Position 4: 2048
Position 5: 2559
Position 6: 3071
Position 7: 3583
Locked-out position: approximately 0 (invalid)
```

Firmware should define threshold ranges for each position instead of checking exact values. A good starting point is to place each threshold halfway between adjacent expected values, then require the decoded position to remain stable for 20-50ms before accepting the change.

# SPI display reserve

The design should reserve pins for a future SPI display. A typical SPI display may need:

- SCK
- MOSI
- CS
- DC
- optional RST
- optional backlight control

Using the MCP23017 for push buttons keeps enough Pico pins available for the display. Direct-to-GPIO wiring for all buttons and switch positions would make the SPI display difficult to add cleanly.

# Interface to DCS

Initial recommendation: USB HID joystick/game-controller firmware using Arduino with the Arduino-Pico core.

Benefits:

- Simple host-side setup
- DCS can bind buttons, encoders, and selector pulses through normal controller bindings
- No DCS-specific protocol required for the first version

DCS-BIOS may be worth considering later if the project needs bidirectional state, display synchronization, or aircraft-specific radio data.

# Firmware stack

Selected stack: Arduino IDE with the Arduino-Pico core.

This is the preferred final firmware environment because the project is a USB HID game-controller device, not just an input test rig. Arduino-Pico provides a familiar sketch workflow while retaining C++ performance and offering built-in USB joystick, keyboard, and mouse support. It is a practical fit on both Windows 11 and macOS.

Suggested implementation order:

1. Bring up the Pico in Arduino IDE with the Arduino-Pico board package.
2. Scan the I2C bus and confirm the MCP23017 address, expected to be `0x20` unless its address jumpers are changed.
3. Configure the 14 MCP23017 pins as `INPUT_PULLUP`; poll both ports every 5ms and debounce button state changes for 20-30ms.
4. Read the two selector ADC inputs; decode selector positions by threshold range and require a stable reading for 20-50ms.
5. Read the seven encoders directly from Pico GPIO.
6. Send button, selector, and encoder events through USB HID to DCS.

Why Arduino-Pico instead of the Pico SDK:

- Arduino-Pico is C++ with a straightforward sketch, library, compile, and upload workflow. It is easier to iterate on than a standalone CMake project.
- It already provides the USB HID joystick/game-controller capability this panel needs.
- The Pico SDK provides the most control over low-level timing and custom USB descriptors, but its toolchain and CMake project setup are more involved. It remains a good future option if this panel eventually needs a custom HID report beyond what Arduino-Pico provides.

Why use Python at all:

- CircuitPython and MicroPython are excellent for quick wiring checks because code can be changed and run rapidly, and CircuitPython has a maintained MCP23017 library.
- CircuitPython can also present a gamepad, but it requires HID configuration in `boot.py` and an additional helper module.
- For this project, Python is useful as a temporary diagnostic tool, not the selected final firmware stack.

Windows 11 and macOS are both suitable for Arduino-Pico. The finished Pico appears to the computer as a standard USB HID device, so DCS does not need a special driver.

## Initial controller sketch

The initial Arduino sketch is [arc210_controller.ino](./arc210_controller/arc210_controller.ino).

Arduino IDE setup:

1. Install the Arduino-Pico board package and select `Raspberry Pi Pico`.
2. Set `Tools -> USB Stack -> Pico SDK`; the Arduino-Pico `Joystick` library is provided by this USB stack.
3. Install `Adafruit MCP23X17` from Library Manager. Its dependencies, including Adafruit BusIO, should install automatically.
4. Upload the sketch with the Pico connected by USB.

The sketch presents one USB joystick with all 32 buttons used and no analog control assigned:

| HID controls | Source |
| --- | --- |
| Buttons 1-14 | MCP23017 push buttons |
| Buttons 15-26 | Encoder 1-6 positive and negative turns |
| Buttons 27-28 | Encoder 7 positive and negative turns |
| Buttons 29-30 | Selector 1 next and previous position pulses |
| Buttons 31-32 | Selector 2 next and previous position pulses |

The Arduino-Pico joystick descriptor supports 32 buttons, so this allocation uses its entire button capacity. The selectors intentionally emit relative next/previous pulses instead of using fourteen more held buttons, keeping the design within that limit. Bind each selector's next/previous buttons to the matching DCS increment/decrement commands. On startup, align the simulator state with the physical selector positions manually.

# Open items before final schematic

- Confirm the SPI display model and pin requirements
- Confirm the final USB HID report: 32-button capacity, encoder behavior, and selector behavior

# PCB Rev A work

The first PCB revision is a panel-sized button carrier. The 14 tactile buttons mount directly to the PCB; the seven encoders and two selectors remain faceplate-mounted and connect through harnesses.

Current design package:

- [PCB design notes](./pcb-revA/arc210-revA-design.md)
- [Mechanical placement reference](./pcb-revA/arc210-revA-mechanical.svg)
- [Preliminary electrical schematic](./pcb-revA/arc210-revA-schematic.svg)
- [KiCad panel reference board](./pcb-revA/ARC210_RevA_panel_reference.kicad_pcb)

Rev A uses a removable Raspberry Pi Pico in two 1x20 sockets, a socketed MCP23017-E/SP DIP-28 IC, and provisional 6x6mm tactile-switch footprints. It is not ready for fabrication until the exact tactile switch, button-cap/plunger arrangement, rotary-control dimensions, mounting method, and connector family are confirmed.

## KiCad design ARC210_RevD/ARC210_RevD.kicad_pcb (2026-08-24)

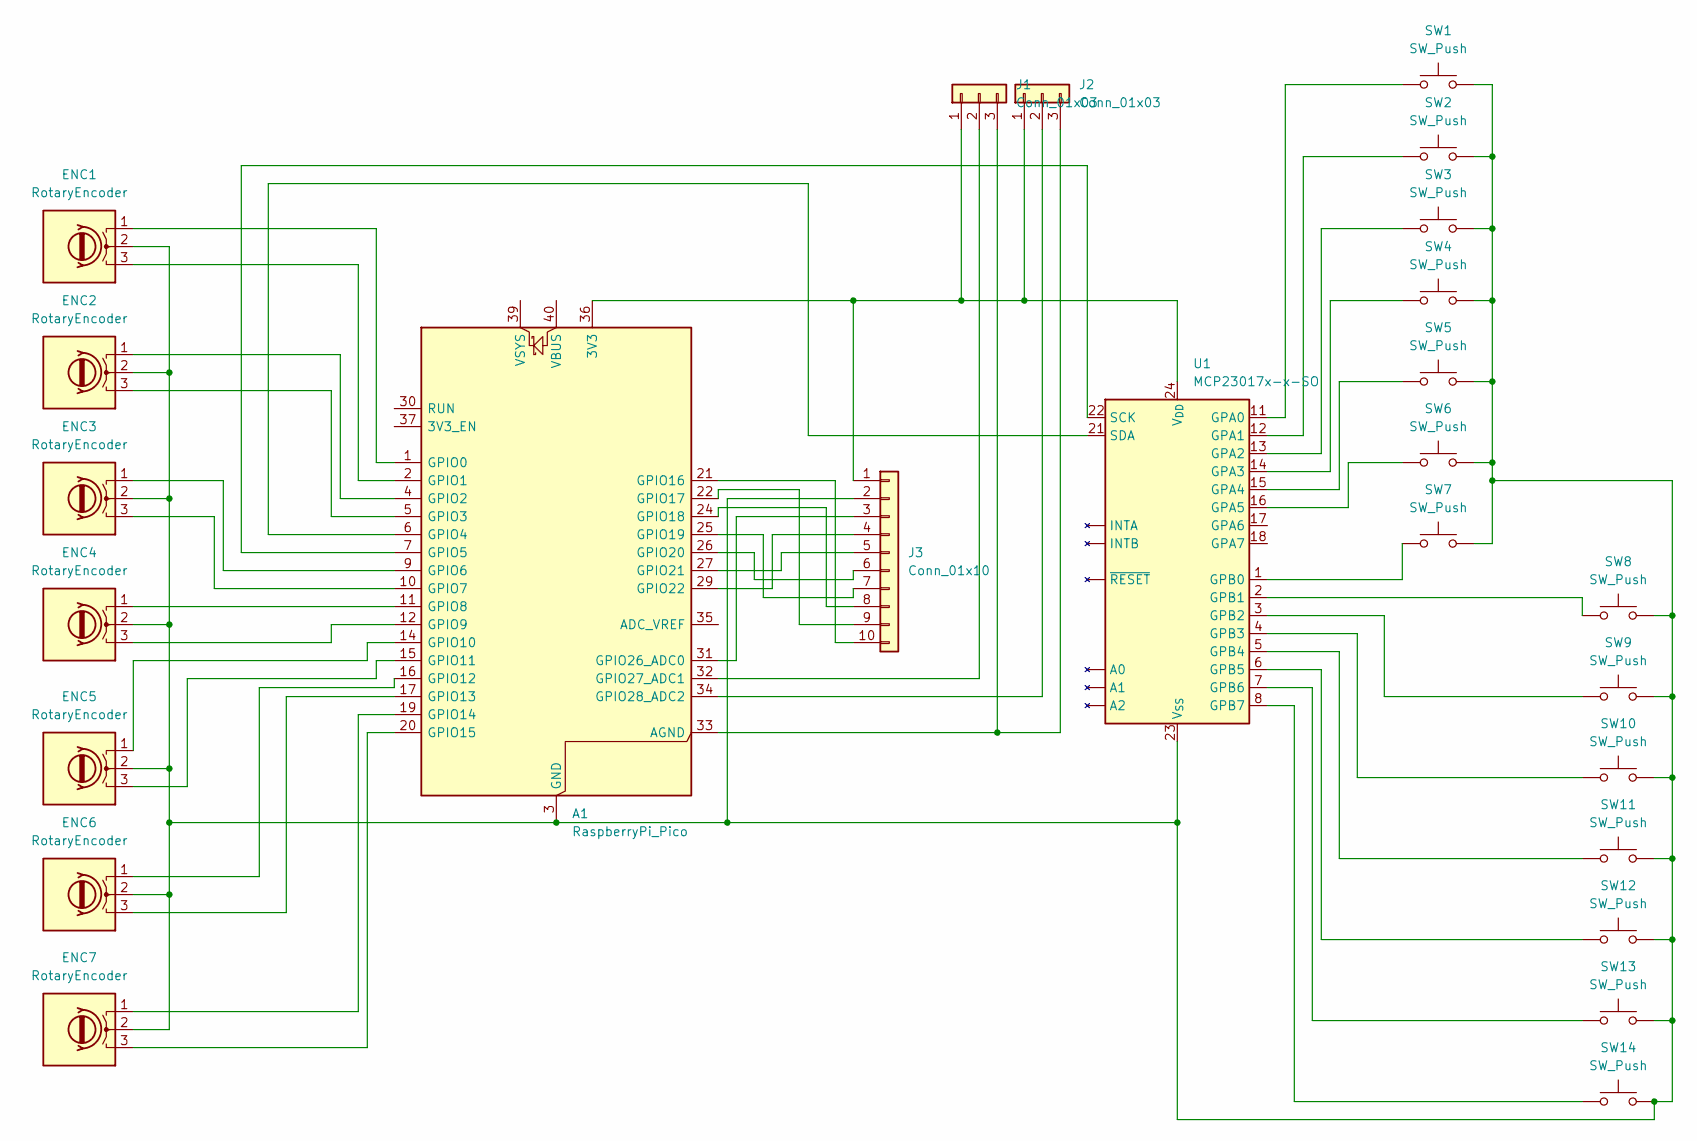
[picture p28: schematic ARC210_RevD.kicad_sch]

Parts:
A1: RaspberryPi_Pico; Pico_mount
ENC1, ENC2, ENC3, ENC4, ENC5, ENC6, ENC7: RotaryEncoder; SolderWire-0.5sqmm_1x03_P4.8mm_D0.9mm_OD2.3mm
J1, J2: Conn_01x03; SolderWire-0.5sqmm_1x03_P4.6mm_D0.9mm_OD2.1mm
J3: Conn_01x10; PinHeader_1x10_P2.54mm_Vertical
SW1, SW2, SW3, SW4, SW5, SW6, SW7, SW8, SW9, SW10, SW11, SW12, SW13, SW14: SW_Push; SW_PUSH_6mm
U1: MCP23017x-x-SO; MCP23017_mount

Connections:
unnamed: A1.36 (3V3), J1.1 (3v3), J2.1 (3v3), J3.1, U1.24 (V_{DD})
unnamed: A1.33 (AGND), J1.3 (GND), J2.3 (GND)
unnamed: A1.1 (GPIO0), ENC1.1 (CLK)
unnamed: A1.2 (GPIO1), ENC1.3 (DATA)
unnamed: A1.4 (GPIO2), ENC2.1 (CLK)
unnamed: A1.5 (GPIO3), ENC2.3 (DATA)
unnamed: A1.6 (GPIO4), U1.21 (SDA)
unnamed: A1.7 (GPIO5), U1.22 (SCK)
unnamed: A1.9 (GPIO6), ENC3.1 (CLK)
unnamed: A1.10 (GPIO7), ENC3.3 (DATA)
unnamed: A1.11 (GPIO8), ENC4.1 (CLK)
unnamed: A1.12 (GPIO9), ENC4.3 (DATA)
unnamed: A1.14 (GPIO10), ENC5.1 (CLK)
unnamed: A1.15 (GPIO11), ENC5.3 (DATA)
unnamed: A1.16 (GPIO12), ENC6.1 (CLK)
unnamed: A1.17 (GPIO13), ENC6.3 (DATA)
unnamed: A1.19 (GPIO14), ENC7.1 (CLK)
unnamed: A1.20 (GPIO15), ENC7.3 (DATA)
unnamed: A1.21 (GPIO16), J3.10 (pin_10)
unnamed: A1.22 (GPIO17), J3.9
unnamed: A1.24 (GPIO18), J3.8
unnamed: A1.25 (GPIO19), J3.7
unnamed: A1.26 (GPIO20), J3.6
unnamed: A1.27 (GPIO21), J3.5
unnamed: A1.29 (GPIO22), J3.4
unnamed: A1.31 (GPIO26_ADC0), J3.3 (pin_3)
unnamed: A1.32 (GPIO27_ADC1), J1.2 (ADC)
unnamed: A1.34 (GPIO28_ADC2), J2.2 (ADC)
unnamed: A1.3 (GND), A1.8 (GND), A1.13 (GND), A1.18 (GND), A1.23 (GND), A1.28 (GND), A1.38 (GND), ENC1.2 (GND), ENC2.2 (GND), ENC3.2 (GND), ENC4.2 (GND), ENC5.2 (GND), ENC6.2 (GND), ENC7.2 (GND), J3.2, SW1.2, SW2.2, SW3.2, SW4.2, SW5.2, SW6.2, SW7.2, SW8.2, SW9.2, SW10.2, SW11.2, SW12.2, SW13.2, SW14.2, U1.23 (V_{SS})
unnamed: SW1.1, U1.11 (GPA0)
unnamed: SW2.1, U1.12 (GPA1)
unnamed: SW3.1, U1.13 (GPA2)
unnamed: SW4.1, U1.14 (GPA3)
unnamed: SW5.1, U1.15 (GPA4)
unnamed: SW6.1, U1.16 (GPA5)
unnamed: SW7.1, U1.1 (GPB0)
unnamed: SW8.1, U1.2 (GPB1)
unnamed: SW9.1, U1.3 (GPB2)
unnamed: SW10.1, U1.4 (GPB3)
unnamed: SW11.1, U1.5 (GPB4)
unnamed: SW12.1, U1.6 (GPB5)
unnamed: SW13.1, U1.7 (GPB6)
unnamed: SW14.1, U1.8 (GPB7)

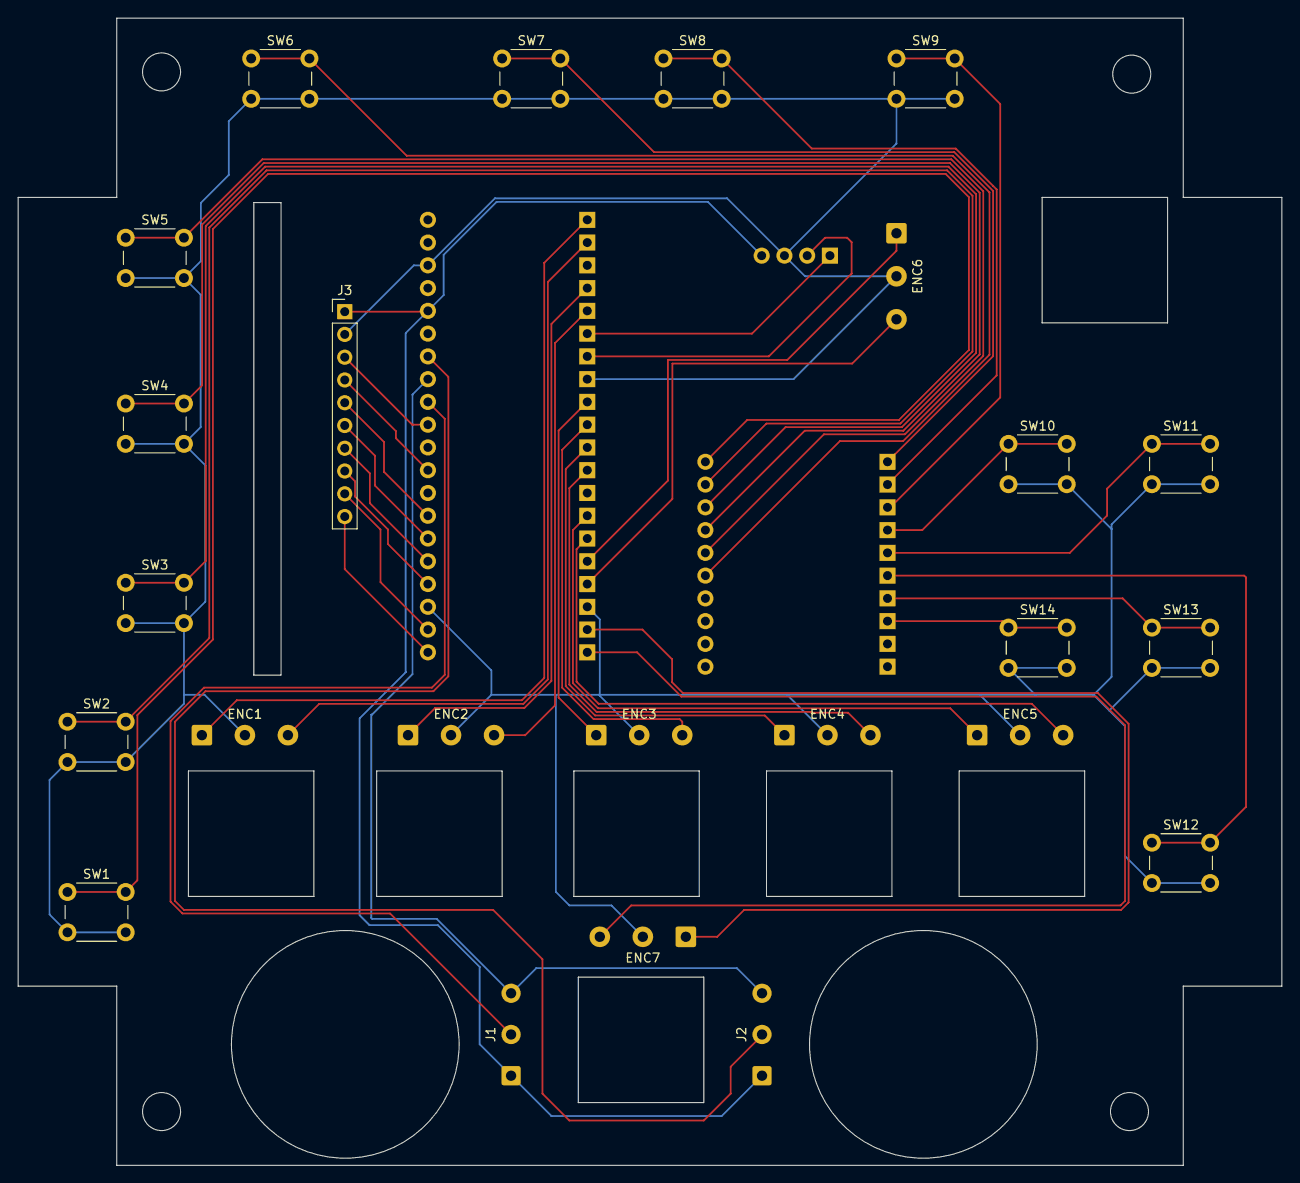
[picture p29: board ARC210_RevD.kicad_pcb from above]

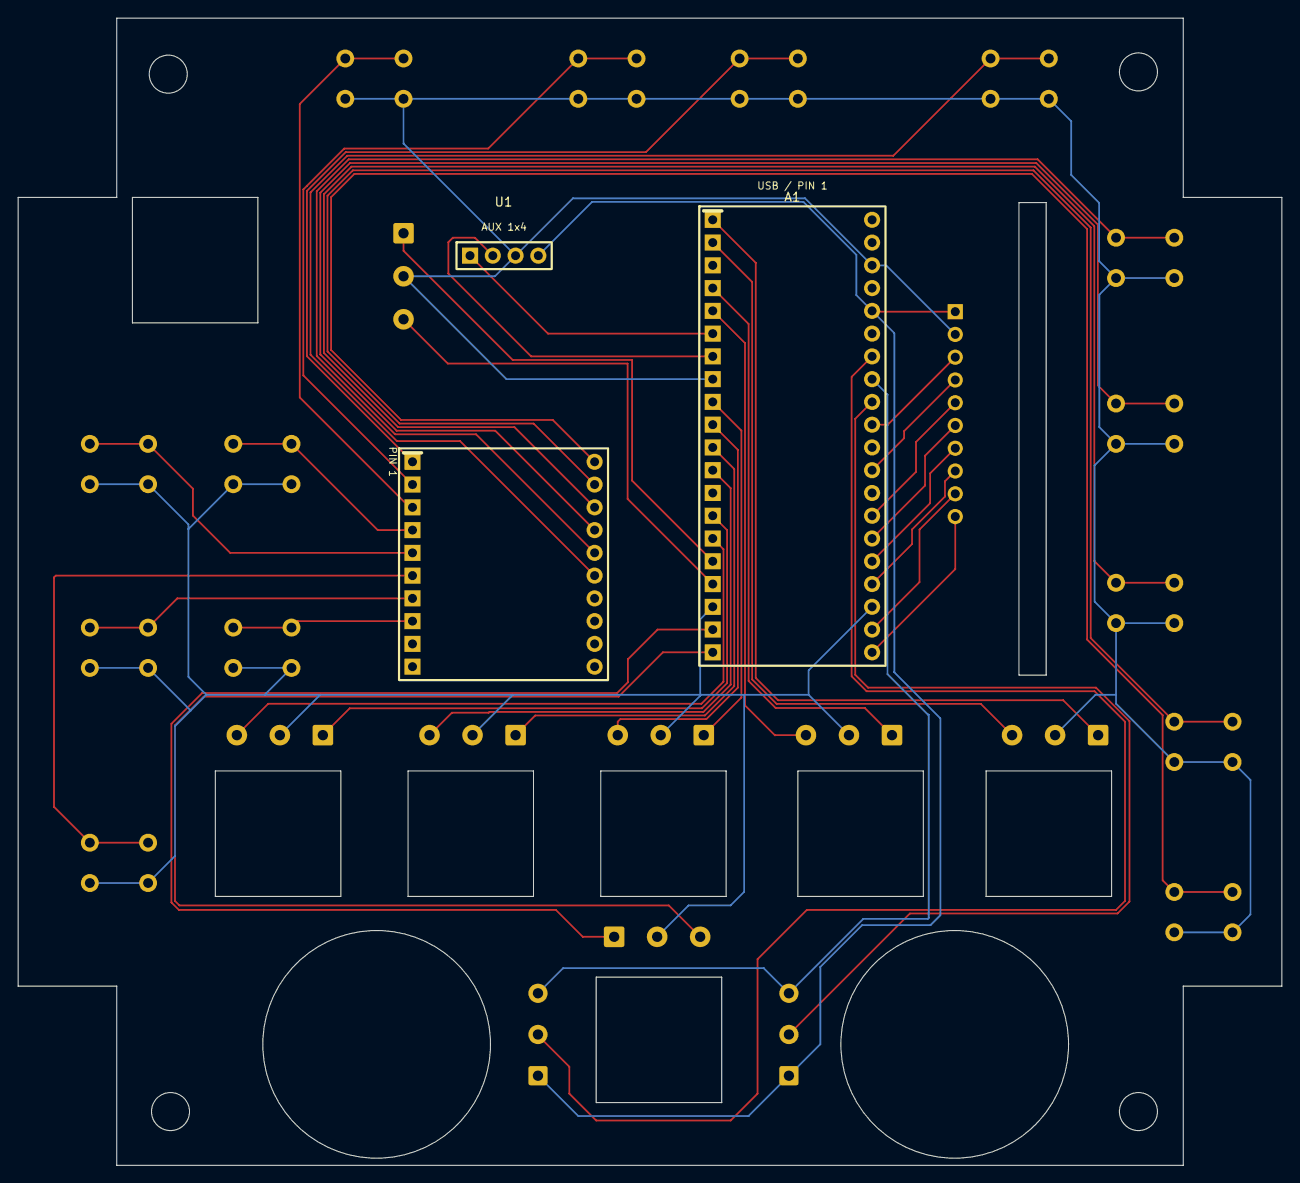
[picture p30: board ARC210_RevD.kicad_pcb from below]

Board: 2 copper layers, 141.0 x 128.0 mm, 26 parts (2 on the bottom side), 43 nets.

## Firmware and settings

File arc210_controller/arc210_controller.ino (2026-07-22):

/*
  ARC-210 DCS controller - Raspberry Pi Pico / Arduino-Pico

  Arduino IDE setup:
    Board: Raspberry Pi Pico
    Tools -> USB Stack: Pico SDK
    Library Manager: install "Adafruit MCP23X17"

  HID layout:
    Buttons  1-14: physical push buttons through the MCP23017
    Buttons 15-28: encoder directions, two buttons per encoder
    Buttons 29-32: selector 1 and 2 next/previous pulses

  Rotary switch positions are absolute in hardware. The HID interface emits
  relative next/previous pulses when a selector position changes, which is
  convenient for DCS bindings. The sim must be synchronized manually after
  boot because an absolute hardware switch cannot know the sim's start state.
*/

#include <Wire.h>
#include "Joystick.h"
#include <Adafruit_MCP23X17.h>

// Arduino-Pico requests a 1ms USB HID polling interval instead of its 10ms default.
int usb_hid_poll_interval = 1;

constexpr bool DEBUG_SERIAL = false;

// Pico wiring allocation.
constexpr uint8_t I2C_SDA_PIN = 4;
constexpr uint8_t I2C_SCL_PIN = 5;
constexpr uint8_t SELECTOR_1_ADC_PIN = 26;
constexpr uint8_t SELECTOR_2_ADC_PIN = 27;

constexpr uint8_t MCP23017_ADDRESS = 0x27;
constexpr uint8_t MCP_BUTTON_COUNT = 16;
constexpr uint32_t MCP_POLL_INTERVAL_MS = 50;
constexpr uint32_t BUTTON_DEBOUNCE_MS = 25;
constexpr uint32_t SELECTOR_DEBOUNCE_MS = 30;
constexpr uint32_t HID_PRESS_MS = 20;
constexpr uint32_t HID_RELEASE_GAP_MS = 10;
constexpr int8_t ENCODER_EDGES_PER_DETENT = 4;


enum HidButton : uint8_t {
  HID_PUSH_BUTTON_1 = 1,
  HID_ENCODER_1_UP = 17,
  HID_ENCODER_1_DOWN = 18,
  HID_ENCODER_2_UP = 19,
  HID_ENCODER_2_DOWN = 20,
  HID_ENCODER_3_UP = 21,
  HID_ENCODER_3_DOWN = 22,
  HID_ENCODER_4_UP = 23,
  HID_ENCODER_4_DOWN = 24,
  HID_ENCODER_5_UP = 25,
  HID_ENCODER_5_DOWN = 26,
  HID_ENCODER_6_UP = 27,
  HID_ENCODER_6_DOWN = 28,
  HID_ENCODER_7_UP = 29,
  HID_ENCODER_7_DOWN = 30,
  HID_SELECTOR_1_OFF = 33,
  HID_SELECTOR_1_TR_G = 34,
  HID_SELECTOR_1_TR = 35,
  HID_SELECTOR_1_ADF = 36,
  HID_SELECTOR_1_CHG_PRST = 37,
  HID_SELECTOR_1_TEST = 38,
  HID_SELECTOR_1_ZERO = 39,
  HID_SELECTOR_2_ECCM_MASTER = 40,
  HID_SELECTOR_2_ECCM = 41,
  HID_SELECTOR_2_PRST = 42,
  HID_SELECTOR_2_MAN = 43,
  HID_SELECTOR_2_MAR = 44,
  HID_SELECTOR_2_243 = 45,
  HID_SELECTOR_2_I2I = 46
};

struct DebouncedInput {
  bool stable;
  bool candidate;
  uint32_t candidateSince;
};

struct EncoderInput {
  uint8_t pinA;
  uint8_t pinB;
  uint8_t positiveButton;
  uint8_t negativeButton;
  uint8_t lastState;
  int8_t edgeAccumulator;
};

struct SelectorInput {
  uint8_t adcPin;
  uint8_t stablePosition;
  uint8_t candidatePosition;
  uint32_t candidateSince;
  uint8_t* buttons;
};

struct PulseButton {
  uint8_t hidButton;
  uint8_t pendingCount;
  bool pressed;
  bool releaseGap;
  uint32_t changedAt;
};

Adafruit_MCP23X17 mcp;
DebouncedInput mcpButtons[MCP_BUTTON_COUNT];

EncoderInput encoders[] = {
  {0, 1, HID_ENCODER_1_UP, HID_ENCODER_1_DOWN, 0, 0},
  {2, 3, HID_ENCODER_2_UP, HID_ENCODER_2_DOWN, 0, 0},
  {6, 7, HID_ENCODER_3_UP, HID_ENCODER_3_DOWN, 0, 0},
  {8, 9, HID_ENCODER_4_UP, HID_ENCODER_4_DOWN, 0, 0},
  {10, 11, HID_ENCODER_5_UP, HID_ENCODER_5_DOWN, 0, 0},
  {12, 13, HID_ENCODER_6_UP, HID_ENCODER_6_DOWN, 0, 0},
  {14, 15, HID_ENCODER_7_UP, HID_ENCODER_7_DOWN, 0, 0},
};
constexpr size_t ENCODER_COUNT = sizeof(encoders) / sizeof(encoders[0]);

uint8_t operationModeSelector[8] = {
  0,
  HID_SELECTOR_1_ZERO,
  HID_SELECTOR_1_TEST,
  HID_SELECTOR_1_CHG_PRST,
  HID_SELECTOR_1_ADF,
  HID_SELECTOR_1_TR,
  HID_SELECTOR_1_TR_G ,
  HID_SELECTOR_1_OFF
};

uint8_t frequencyModeSelector[8] = {
  0,
  HID_SELECTOR_2_I2I,
  HID_SELECTOR_2_243,
  HID_SELECTOR_2_MAR,
  HID_SELECTOR_2_MAN,
  HID_SELECTOR_2_PRST,
  HID_SELECTOR_2_ECCM,
  HID_SELECTOR_2_ECCM_MASTER
};

SelectorInput selectors[] = {
  {SELECTOR_1_ADC_PIN, 0,0,0, frequencyModeSelector},
  {SELECTOR_2_ADC_PIN, 0,0,0, operationModeSelector},
};

constexpr size_t SELECTOR_COUNT = sizeof(selectors) / sizeof(selectors[0]);

PulseButton pulseButtons[] = {
  {HID_ENCODER_1_UP, 0, false, false, 0},
  {HID_ENCODER_1_DOWN, 0, false, false, 0},
  {HID_ENCODER_2_UP, 0, false, false, 0},
  {HID_ENCODER_2_DOWN, 0, false, false, 0},
  {HID_ENCODER_3_UP, 0, false, false, 0},
  {HID_ENCODER_3_DOWN, 0, false, false, 0},
  {HID_ENCODER_4_UP, 0, false, false, 0},
  {HID_ENCODER_4_DOWN, 0, false, false, 0},
  {HID_ENCODER_5_UP, 0, false, false, 0},
  {HID_ENCODER_5_DOWN, 0, false, false, 0},
  {HID_ENCODER_6_UP, 0, false, false, 0},
  {HID_ENCODER_6_DOWN, 0, false, false, 0},
  {HID_ENCODER_7_UP, 0, false, false, 0},
  {HID_ENCODER_7_DOWN, 0, false, false, 0},
  {HID_SELECTOR_1_OFF, 0, false, false, 0},
  {HID_SELECTOR_1_TR_G, 0, false, false, 0},
  {HID_SELECTOR_1_TR, 0, false, false, 0},
  {HID_SELECTOR_1_ADF, 0, false, false, 0},
  {HID_SELECTOR_1_CHG_PRST, 0, false, false, 0},
  {HID_SELECTOR_1_TEST, 0, false, false, 0},
  {HID_SELECTOR_1_ZERO, 0, false, false, 0},
  {HID_SELECTOR_2_ECCM_MASTER, 0, false, false, 0},
  {HID_SELECTOR_2_ECCM, 0, false, false, 0},
  {HID_SELECTOR_2_PRST, 0, false, false, 0},
  {HID_SELECTOR_2_MAN, 0, false, false, 0},
  {HID_SELECTOR_2_MAR, 0, false, false, 0},
  {HID_SELECTOR_2_243, 0, false, false, 0},
  {HID_SELECTOR_2_I2I, 0, false, false, 0}
};
constexpr size_t PULSE_BUTTON_COUNT = sizeof(pulseButtons) / sizeof(pulseButtons[0]);

uint32_t lastMcpPollAt = 0;
uint32_t lastSelectorPollAt = 0;
bool hidDirty = false;

bool elapsed(uint32_t now, uint32_t since, uint32_t interval) {
  return static_cast<uint32_t>(now - since) >= interval;
}

uint8_t readEncoderState(const EncoderInput &encoder) {
  return (digitalRead(encoder.pinA) ? 0b10 : 0) |
         (digitalRead(encoder.pinB) ? 0b01 : 0);
}

PulseButton *pulseButtonFor(uint8_t hidButton) {
  for (size_t index = 0; index < PULSE_BUTTON_COUNT; ++index) {
    if (pulseButtons[index].hidButton == hidButton) {
      return &pulseButtons[index];
    }
  }
  return nullptr;
}

void setHidButton(uint8_t hidButton, bool pressed) {
  Joystick.button(hidButton, pressed);
  if (DEBUG_SERIAL) {
    Serial.printf("Set Button %d \n\r", hidButton);
  }
  hidDirty = true;
}

void queuePulse(uint8_t hidButton, uint32_t now) {
  PulseButton *pulse = pulseButtonFor(hidButton);
  if (pulse == nullptr) {
    return;
  }

  if (!pulse->pressed && !pulse->releaseGap) {
    pulse->pressed = true;
    pulse->changedAt = now;
    setHidButton(hidButton, true);
  } else if (pulse->pendingCount < 255) {
    ++pulse->pendingCount;
  }
}

void servicePulseButtons(uint32_t now) {
  for (size_t index = 0; index < PULSE_BUTTON_COUNT; ++index) {
    PulseButton &pulse = pulseButtons[index];

    if (pulse.pressed && elapsed(now, pulse.changedAt, HID_PRESS_MS)) {
      pulse.pressed = false;
      pulse.releaseGap = true;
      pulse.changedAt = now;
      setHidButton(pulse.hidButton, false);
      continue;
    }

    if (pulse.releaseGap && elapsed(now, pulse.changedAt, HID_RELEASE_GAP_MS)) {
      pulse.releaseGap = false;
      if (pulse.pendingCount > 0) {
        --pulse.pendingCount;
        pulse.pressed = true;
        pulse.changedAt = now;
        setHidButton(pulse.hidButton, true);
      }
    }
  }
}

void initialiseMcpButtons(uint32_t now) {
  const uint16_t rawPins = mcp.readGPIOAB();
  for (uint8_t pin = 0; pin < MCP_BUTTON_COUNT; ++pin) {
    const bool pressed = !(rawPins & (1u << pin));
    mcpButtons[pin] = {pressed, pressed, now};
    setHidButton(HID_PUSH_BUTTON_1 + pin, pressed);
  }
}

void updateMcpButtons(uint32_t now) {
  if (!elapsed(now, lastMcpPollAt, MCP_POLL_INTERVAL_MS)) {
    return;
  }
  lastMcpPollAt = now;

  const uint16_t rawPins = mcp.readGPIOAB();
  for (uint8_t pin = 0; pin < MCP_BUTTON_COUNT; ++pin) {
    const bool pressed = !(rawPins & (1u << pin));
    DebouncedInput &button = mcpButtons[pin];

    if (pressed != button.candidate) {
      button.candidate = pressed;
      button.candidateSince = now;
    }

    if (button.stable != button.candidate &&
      elapsed(now, button.candidateSince, BUTTON_DEBOUNCE_MS)) {
      button.stable = button.candidate;
      setHidButton(HID_PUSH_BUTTON_1 + pin, button.stable);
    }
  }
}

void updateEncoders(uint32_t now) {
  // Transition table for a two-bit quadrature encoder. Reverse the two wires
  // for one encoder, or swap its positive/negative button numbers, if needed.
  static constexpr int8_t QUADRATURE_TRANSITIONS[16] = {
    0, -1, 1, 0,
    1, 0, 0, -1,
    -1, 0, 0, 1,
    0, 1, -1, 0,
  };

  for (size_t index = 0; index < ENCODER_COUNT; ++index) {
    EncoderInput &encoder = encoders[index];
    const uint8_t state = readEncoderState(encoder);
    const int8_t transition = QUADRATURE_TRANSITIONS[(encoder.lastState << 2) | state];
    encoder.lastState = state;

    if (transition == 0) {
      continue;
    }

    encoder.edgeAccumulator += transition;
    if (encoder.edgeAccumulator >= ENCODER_EDGES_PER_DETENT) {
      encoder.edgeAccumulator = 0;
      queuePulse(encoder.positiveButton, now);
    } else if (encoder.edgeAccumulator <= -ENCODER_EDGES_PER_DETENT) {
      encoder.edgeAccumulator = 0;
      queuePulse(encoder.negativeButton, now);
    }
  }
}

uint8_t readSelectorPosition(uint8_t adcPin) {
  const uint16_t raw = analogRead(adcPin);
  const uint8_t position = static_cast<uint8_t>((raw + 480) / 512);
  return position;
}

void emitSelectorSteps(const SelectorInput &selector, uint8_t from, uint8_t to, uint32_t now) {
  const uint8_t pulseButton = selector.buttons[to - 1];
  if (DEBUG_SERIAL) {
    Serial.printf("Selector: pin %d, button: %d, position: %d \n", selector.adcPin, pulseButton, to);
  }
  queuePulse(pulseButton, now);
}

void initialiseSelectors(uint32_t now) {
  for (size_t index = 0; index < SELECTOR_COUNT; ++index) {
    SelectorInput &selector = selectors[index];
    const uint8_t position = readSelectorPosition(selector.adcPin);
    selector.stablePosition = position;
    selector.candidatePosition = position;
    selector.candidateSince = now;
  }
}

void updateSelectors(uint32_t now) {
  if (!elapsed(now, lastSelectorPollAt, MCP_POLL_INTERVAL_MS)) {
    return;
  }
  lastSelectorPollAt = now;

  for (size_t index = 0; index < SELECTOR_COUNT; ++index) {
    SelectorInput &selector = selectors[index];
    const uint8_t position = readSelectorPosition(selector.adcPin);

    if (position != selector.candidatePosition) {
      selector.candidatePosition = position;
      selector.candidateSince = now;
    }

    if (position != selector.stablePosition &&
        elapsed(now, selector.candidateSince, SELECTOR_DEBOUNCE_MS)) {
      const uint8_t previous = selector.stablePosition;
      selector.stablePosition = position;

      // Do not emit a command while a selector is on its invalid terminal.
      if (previous != position) {
        emitSelectorSteps(selector, previous, position, now);
      }
    }
  }
}

void setup() {
  if (DEBUG_SERIAL) {
    Serial.begin(115200);
    delay(250);
    Serial.println("ARC-210 controller starting");
  }

  analogReadResolution(12);

  Wire.setSDA(I2C_SDA_PIN);
  Wire.setSCL(I2C_SCL_PIN);
  Wire.begin();
  Wire.setClock(400000);

  while (!mcp.begin_I2C(MCP23017_ADDRESS, &Wire)) {
    if (DEBUG_SERIAL) {
      Serial.println("MCP23017 not found. Check power, GND, SDA, SCL, and address jumpers.");
    }
    delay(1000);
  }

  for (uint8_t pin = 0; pin < MCP_BUTTON_COUNT; ++pin) {
    mcp.pinMode(pin, INPUT_PULLUP);
  }

  for (size_t index = 0; index < ENCODER_COUNT; ++index) {
    EncoderInput &encoder = encoders[index];
    pinMode(encoder.pinA, INPUT_PULLUP);
    pinMode(encoder.pinB, INPUT_PULLUP);
    encoder.lastState = readEncoderState(encoder);
  }

  Joystick.begin();
  Joystick.useManualSend(true);

  const uint32_t now = millis();
  initialiseMcpButtons(now);
  initialiseSelectors(now);
  Joystick.send_now();
  hidDirty = false;

  if (DEBUG_SERIAL) {
    Serial.println("MCP23017 found; USB joystick ready.");
  }
}

void loop() {
  const uint32_t now = millis();
  updateEncoders(now);
  updateMcpButtons(now);
  updateSelectors(now);
  servicePulseButtons(now);

  if (hidDirty) {
    Joystick.send_now();
    hidDirty = false;
  }
}

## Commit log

2026-08-17 Updated to add PCB
    [ARC210_RevD.kicad_pcb, ARC210_RevD.kicad_sch]
2026-08-23 Alpha Build
    [ARC210_RevD.kicad_pcb, ARC210_RevD.kicad_sch, arc210_open_tray.scad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]
2026-08-24 Alpha Build
    updated knobs
    [ARC-210 Channel Knob.stl, ARC-210 Freq Knob.stl, ARC-210 Mode Knob.stl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]
